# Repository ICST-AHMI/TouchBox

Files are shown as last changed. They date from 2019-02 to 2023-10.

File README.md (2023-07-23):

# The TouchBox MK3
A low-cost DIY interface for tracking the position multiple fingers (currently up to three) in contact with its top surface, measuring their contact areas as well as 3D (normal and lateral) forces, and providing rich vibrotactile feedback.

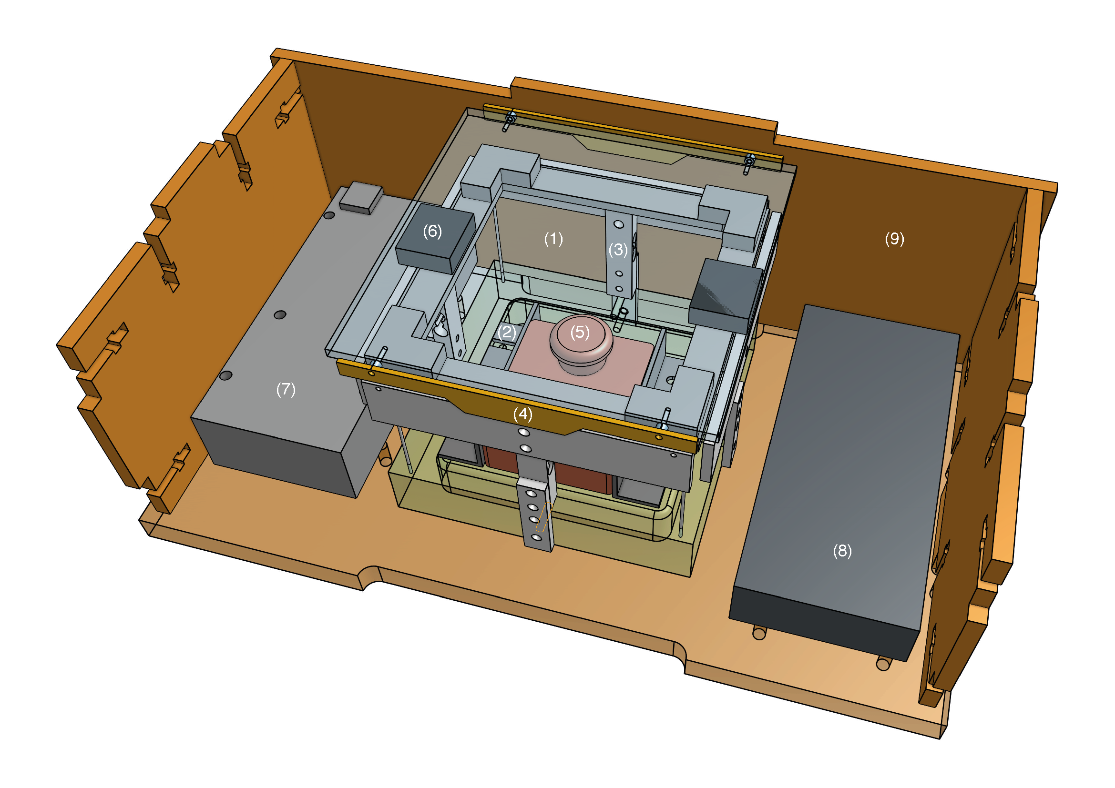
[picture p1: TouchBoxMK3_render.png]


---
## Content

* Software:
	1. GUI - based on [MaxMSP](https://cycling74.com) (No license required to run this patch).
	2. Example Patches for vibration and optional audio feedback.
	3. [Arduino](http://arduino.cc/) code.
	4. [OpenMV](https://openmv.io/) code.

* Hardware:
	1. list of required hardware (file HardwareList.md).
	2. 3D models (STEP) and plans (PDF) - made with [OnShape](https://onshape.com).
	3. electronics schematics - made with [Eagle](https://www.autodesk.com/products/eagle/overview).

* README.md (this).

---
## Software

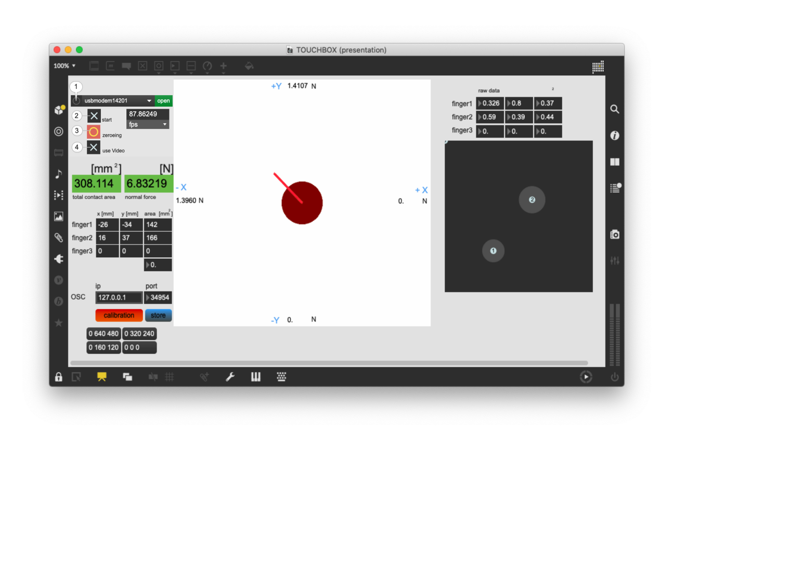
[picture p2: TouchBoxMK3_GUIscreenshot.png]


* Follow these steps:
	1. Refresh the list of available devices and select the Arduino (usually labeled 'usbmodem####');
	2. Toggle 'start';
	3. Reset force sensors. Press 'zeroing';
	4. For finger tracking via an openMV module, switch on 'use Video'.

* For sending the data to another application via OSC, enter ip and port numbers.

* If you need to calibrate the software, press "calibration" and once done "store".

## OSC communication protocol

### /touch/weight \<force>
force = float in [Newton]

### /touch/shear/up \<force>
force = float in [Newton]

### /touch/shear/down \<force>
force = float in [Newton]

### /touch/shear/left \<force>
force = float in [Newton]

### /touch/shear/right \<force>
force = float in [Newton]

### /touch/finger \<id> \<posX> \<posY> \<area>
id = int (identification id of finger, starts with 0)

posX = int in [pixel from center]

posY = int in [pixel from center]

area = float in [mm^2]

## Installation

For running the GUI, you need to install [MaxMSP](https://cycling74.com).
No license needed.

---
## Licenses

The Arduino and openMV code is licensed under [GNU](http://www.gnu.org/licenses/).

For everything else:  



---
## Release



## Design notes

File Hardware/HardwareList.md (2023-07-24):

# TouchBox MK3 hardware list

* Sensors
  * 1x normal force sensor - Micro Load Cell (5 kg) - Model CZL635
  * 4x lateral force sensor (one per side) - Micro Load Cell (780 g) - Model CZL616C
  * 1x OpenMV camera - Model M7 or compatible
  * 1x ultra wide angle lens for OpenMV camera

* Vibrotactile feedback
  * 2x compact voice-coil actuator (to be attached to the touch pannel) - Lofelt L5
  * 1x stereo amplifier - Dayton Audio DTA-2

* Misc electronics
  * 1x Arduino Mega 2560
  * 1x PCB - custom Arduino Mega shield
  * 2x PCB - custom for IR lighting touch panel
  * 5x amplifier for Micro Load Cells - Model INA125P-ND
  * 4x 43 Ohm Resistor for amplification of 780 g
  * 1x 75 Ohm Resistor for amplification of 5 kg
  * 12x IR LED's - (850nm) - Model SMD vsmy3850
  * Mac or Windows computer compatible with Cycling '74 Max.
  * 4ch audio interface (only required if separate audio stream is needed, if
    not you may go ahead with any internal audio interface)

* Custom hardware
  * 1x transparent touch panel - Plexiglass - 110 x 110 x 3 mm
  * 4x L-shaped distancers 20 x 20 x 10 mm + foam-rubber coupling spacers 2 mm
  * 1x shear base plate - steel slate 98 x 98 x 3 mm
  <!-- * 4x feather steel support rods 0.8 x 52 mm -->
  * 1x presure base support -  custom milled High Density Polyethylene block 100 x 100 x 20 mm
  <!-- * 1x normal force plate - custom milled aluminium block 85 x 85 x 2 mm -->
  * 4x side plate (shear sensor/support plate coupling element) - aluminium 96 x 20 x 3 mm
  * 4x shear sensor/pressure base coupling plates 35 x 9 x 3 mm
  * 2x L-shaped camera grips
  * MDF for optional laser-cut enclosure

* Off-the-shelf hardware
  * 3x distance washer - M5 x 18 mm
  * 1x countersink screw - M5 x 25 mm
  * 12x socket head cap screw - M4 x 25 mm
  * 4x countersink screw - mM4 x 30 mm
  * 4x feather steel wire (one per corner) - 0.8 x 35 mm
  * 4x actuator screw (two per actuator) - countersink screw - M3 x 40 mm
  * 4x rubber foam spacer (one at each corner)
  <!--* 8x headless screw (two per side plate) - M3 x 4 mm -->
  * 4x IR LED PCB screws - M2 x 10 mm
  * 4x IR LED PCB distance spacer - 2 mm
  * Cables and connectors as needed

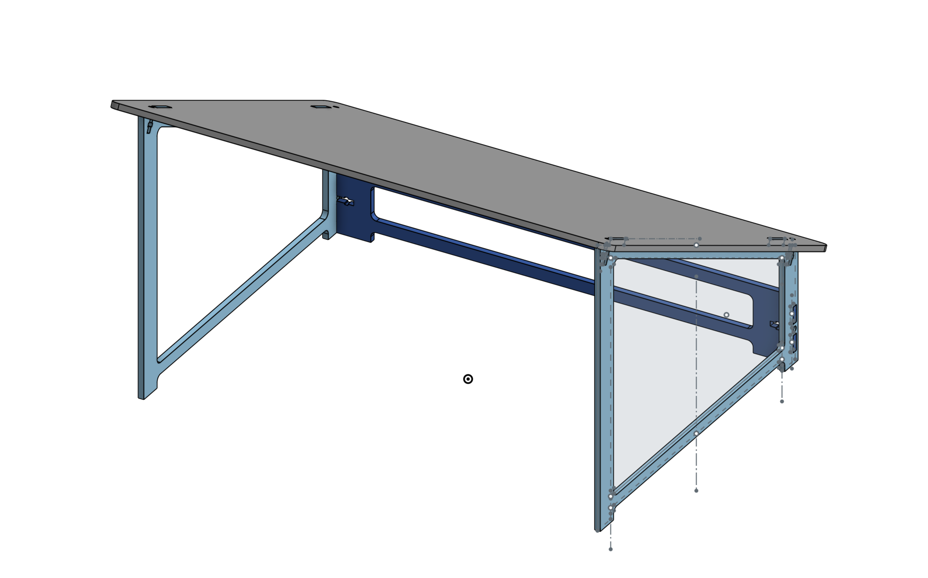
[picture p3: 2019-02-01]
Hardware/design/Shield/Shield.png

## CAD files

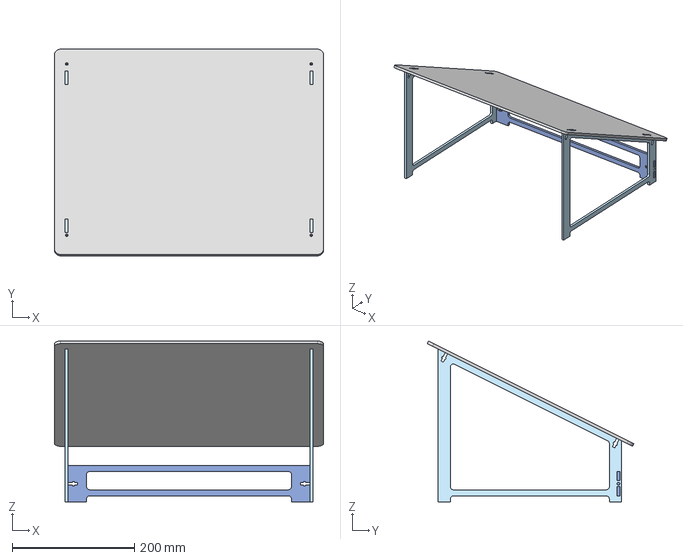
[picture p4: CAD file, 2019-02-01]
Hardware/design/Shield/Shield.step
440.0 x 338.0 x 263.3 mm

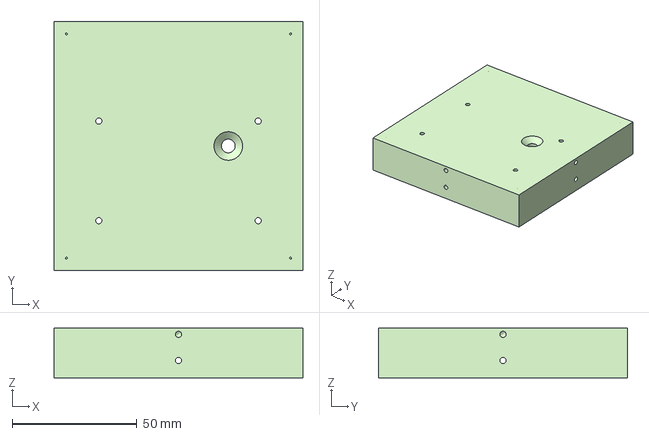
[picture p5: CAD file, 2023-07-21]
Hardware/design/TouchBox/PressureBase.step
100.0 x 100.0 x 20.0 mm

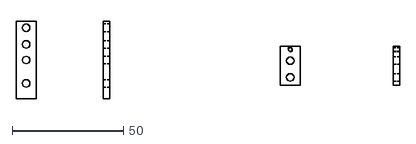
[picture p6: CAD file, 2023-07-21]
Hardware/design/TouchBox/ShearConnectors.dxf
172.5 x 35.0

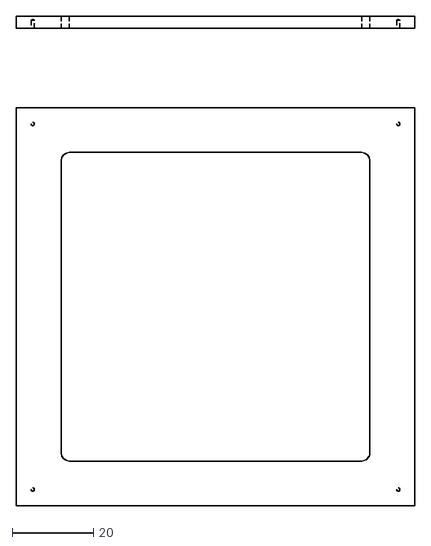
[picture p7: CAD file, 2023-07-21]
Hardware/design/TouchBox/ShearBase.dxf
98.0 x 120.5

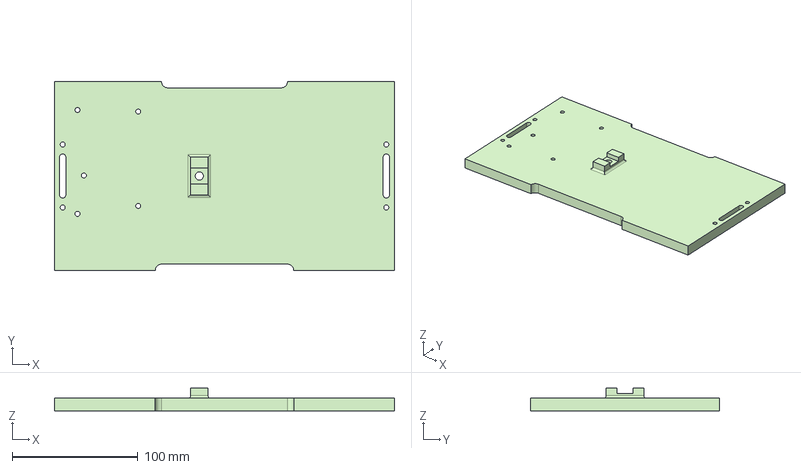
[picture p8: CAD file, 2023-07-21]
Hardware/design/TouchBox/Base.step
270.0 x 150.0 x 18.0 mm

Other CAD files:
Hardware/design/Shield/Shield.x_t

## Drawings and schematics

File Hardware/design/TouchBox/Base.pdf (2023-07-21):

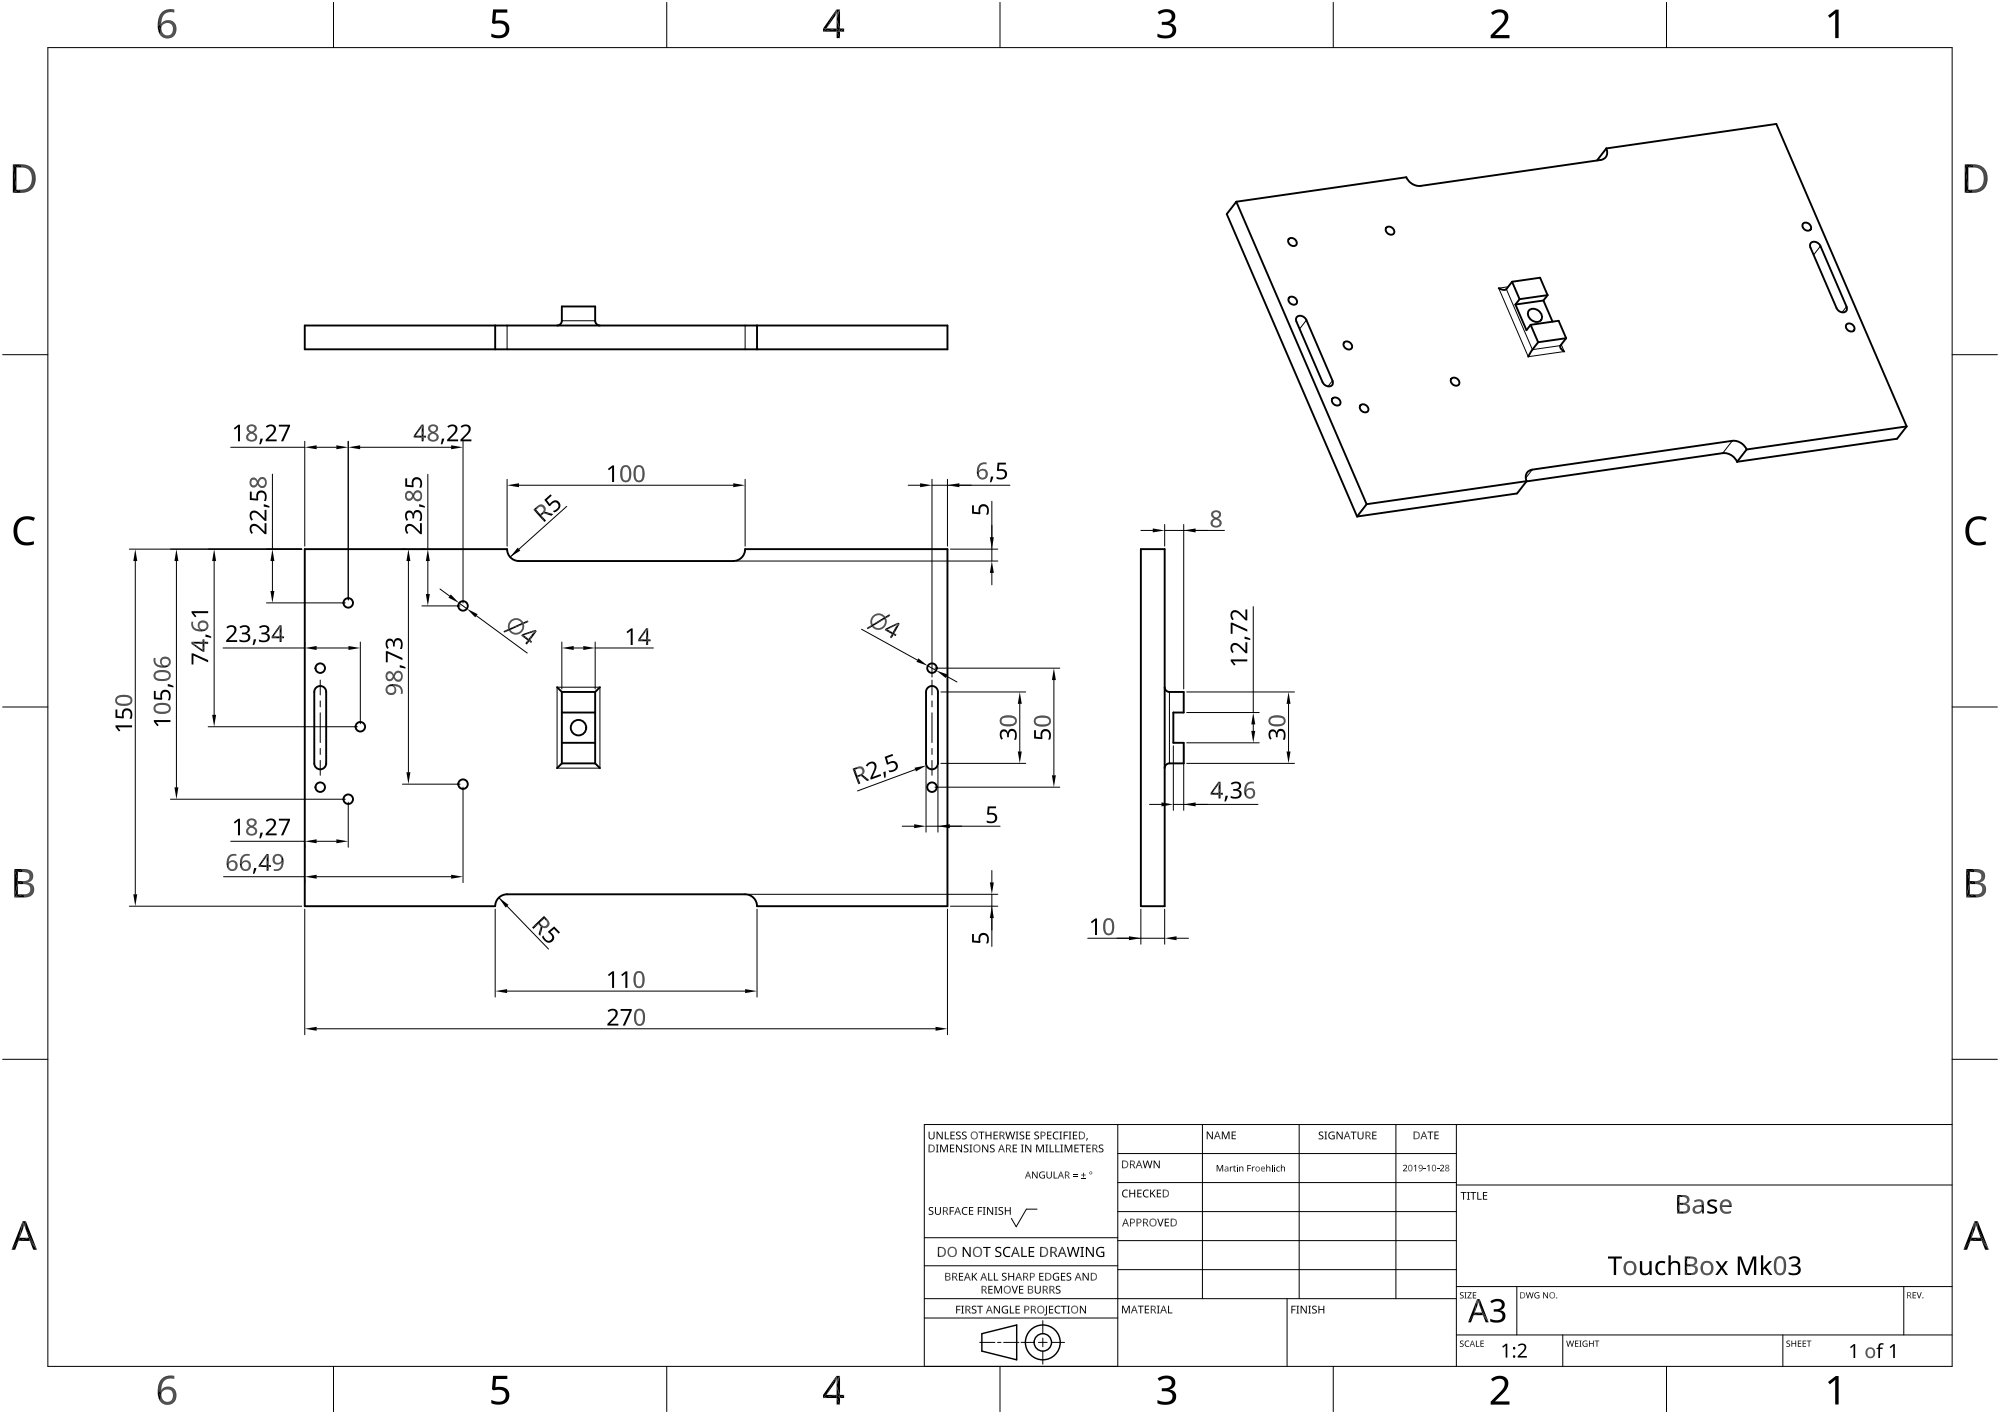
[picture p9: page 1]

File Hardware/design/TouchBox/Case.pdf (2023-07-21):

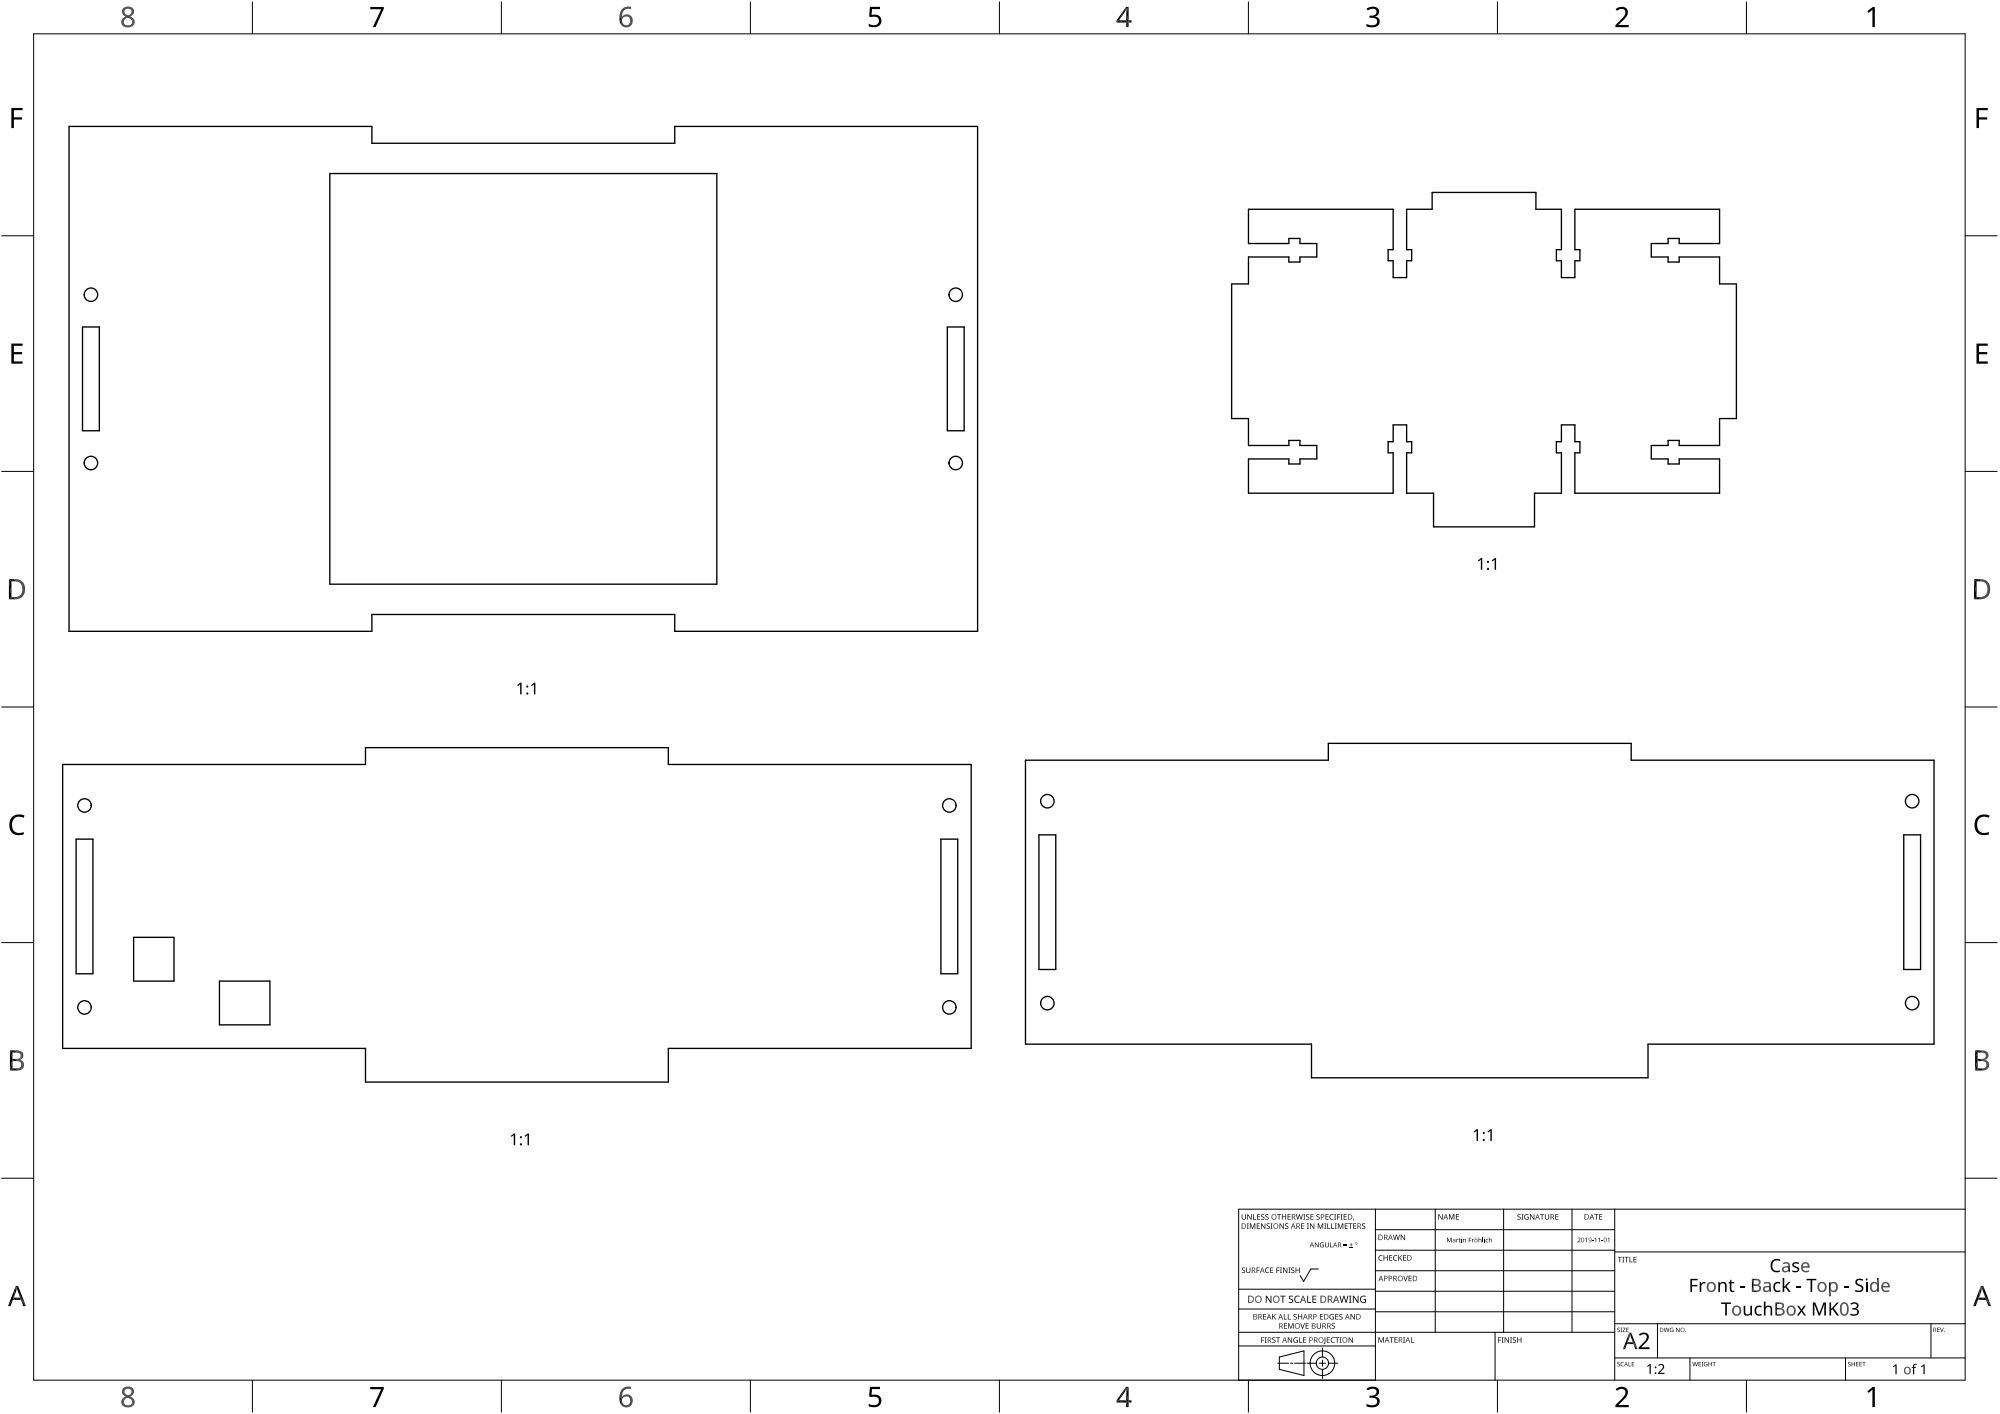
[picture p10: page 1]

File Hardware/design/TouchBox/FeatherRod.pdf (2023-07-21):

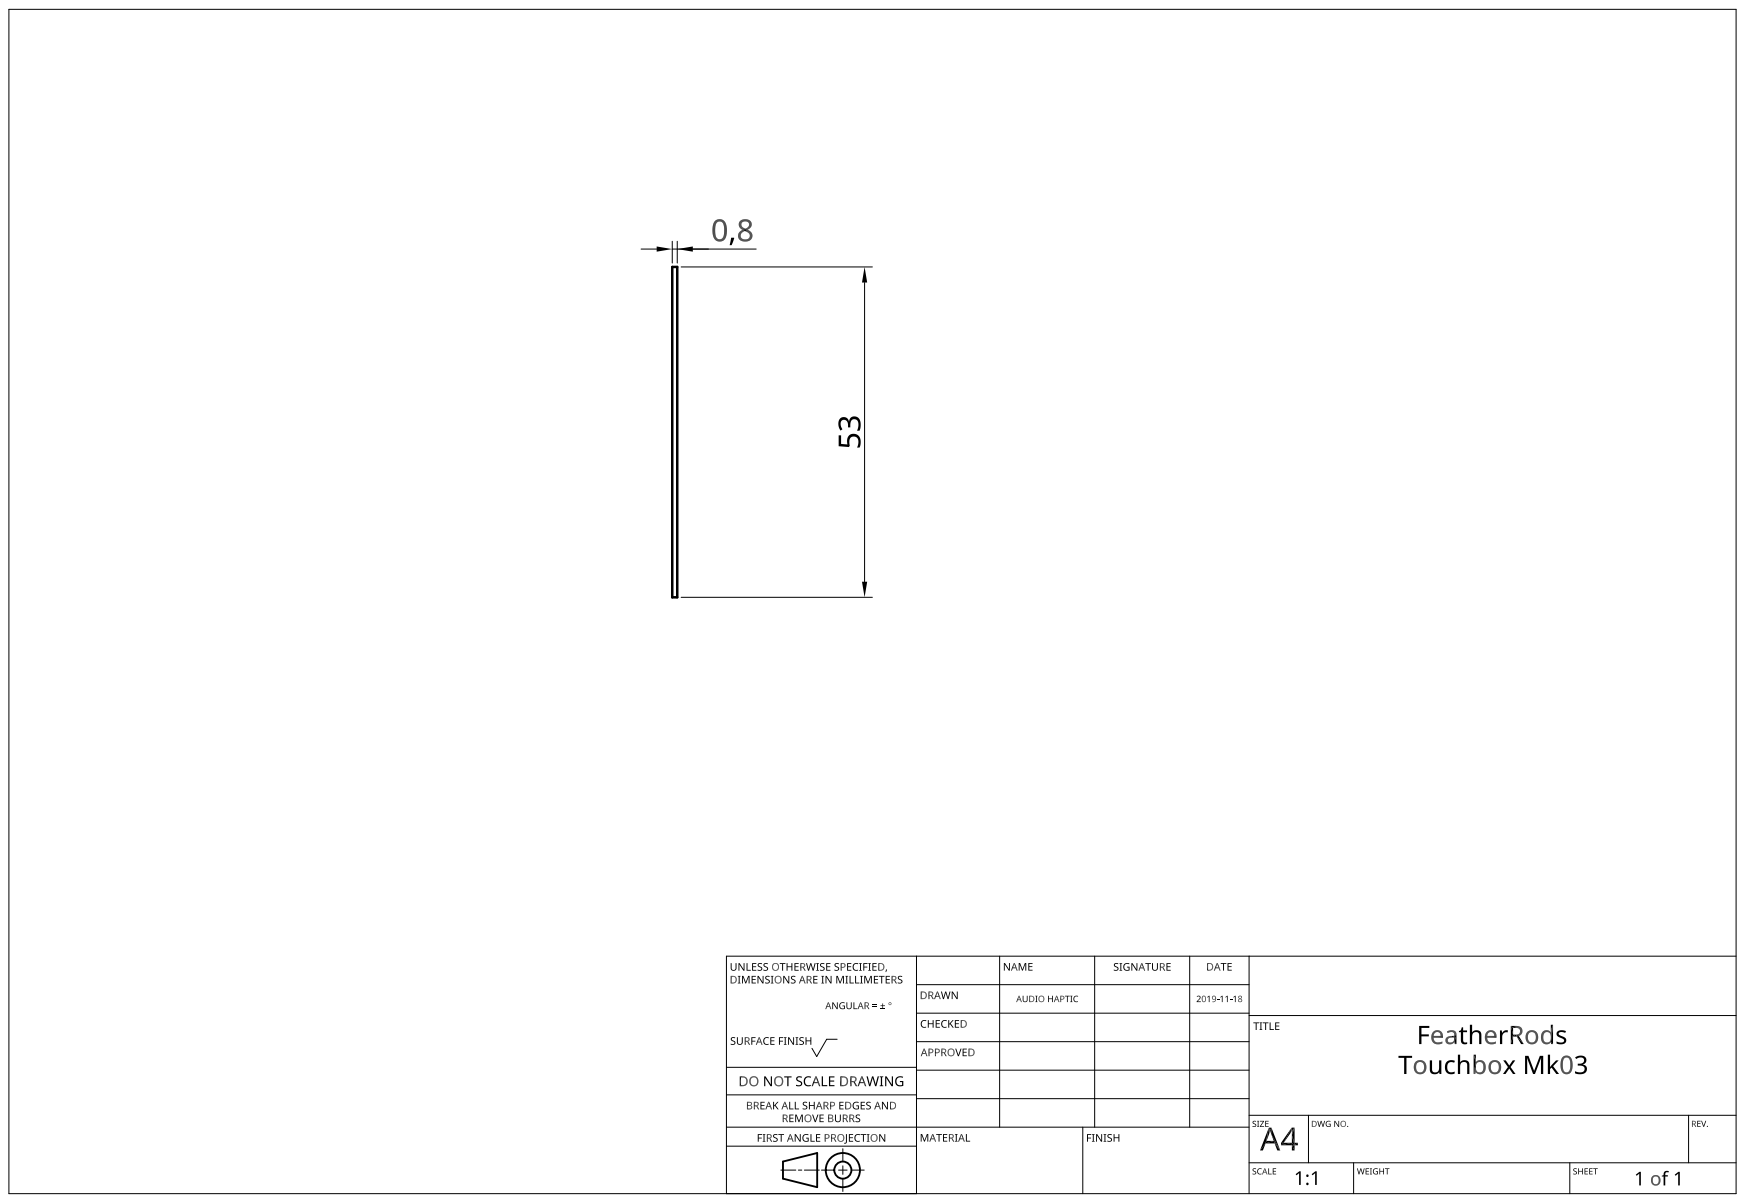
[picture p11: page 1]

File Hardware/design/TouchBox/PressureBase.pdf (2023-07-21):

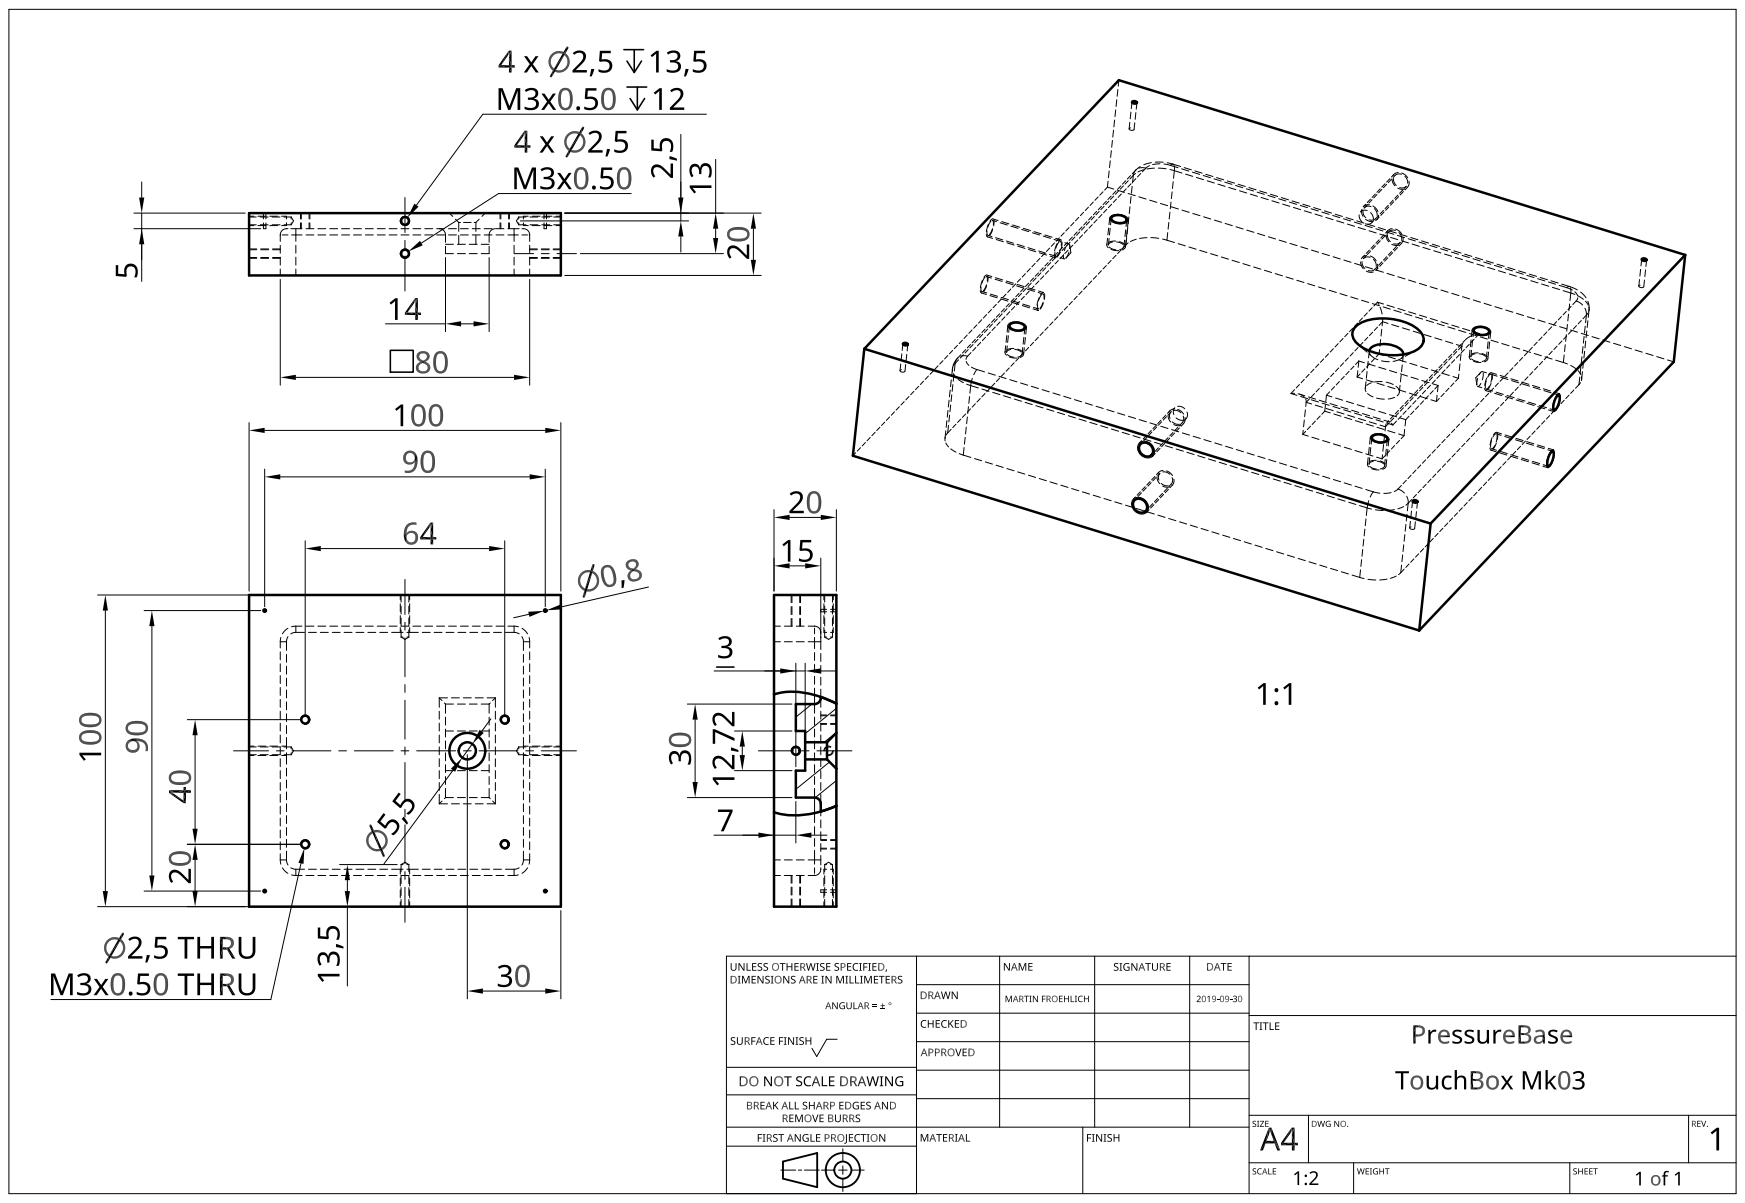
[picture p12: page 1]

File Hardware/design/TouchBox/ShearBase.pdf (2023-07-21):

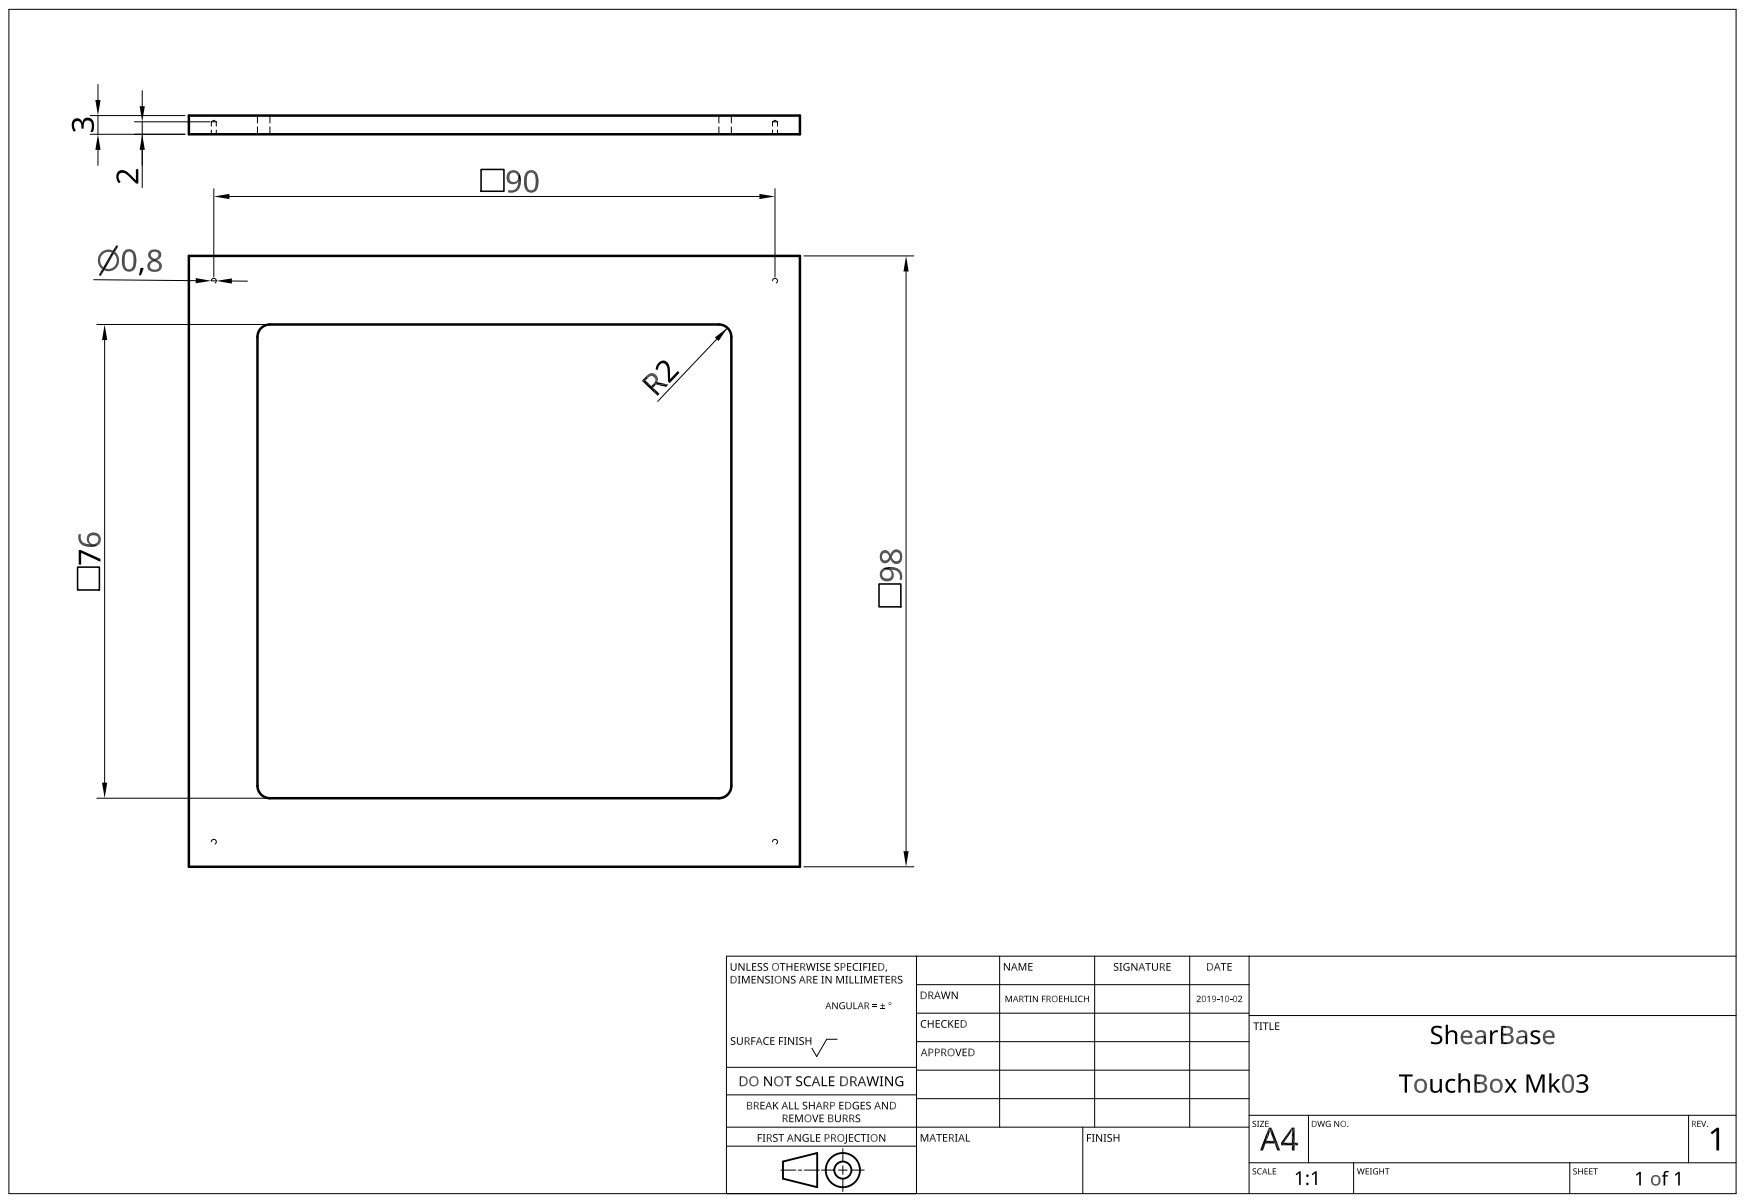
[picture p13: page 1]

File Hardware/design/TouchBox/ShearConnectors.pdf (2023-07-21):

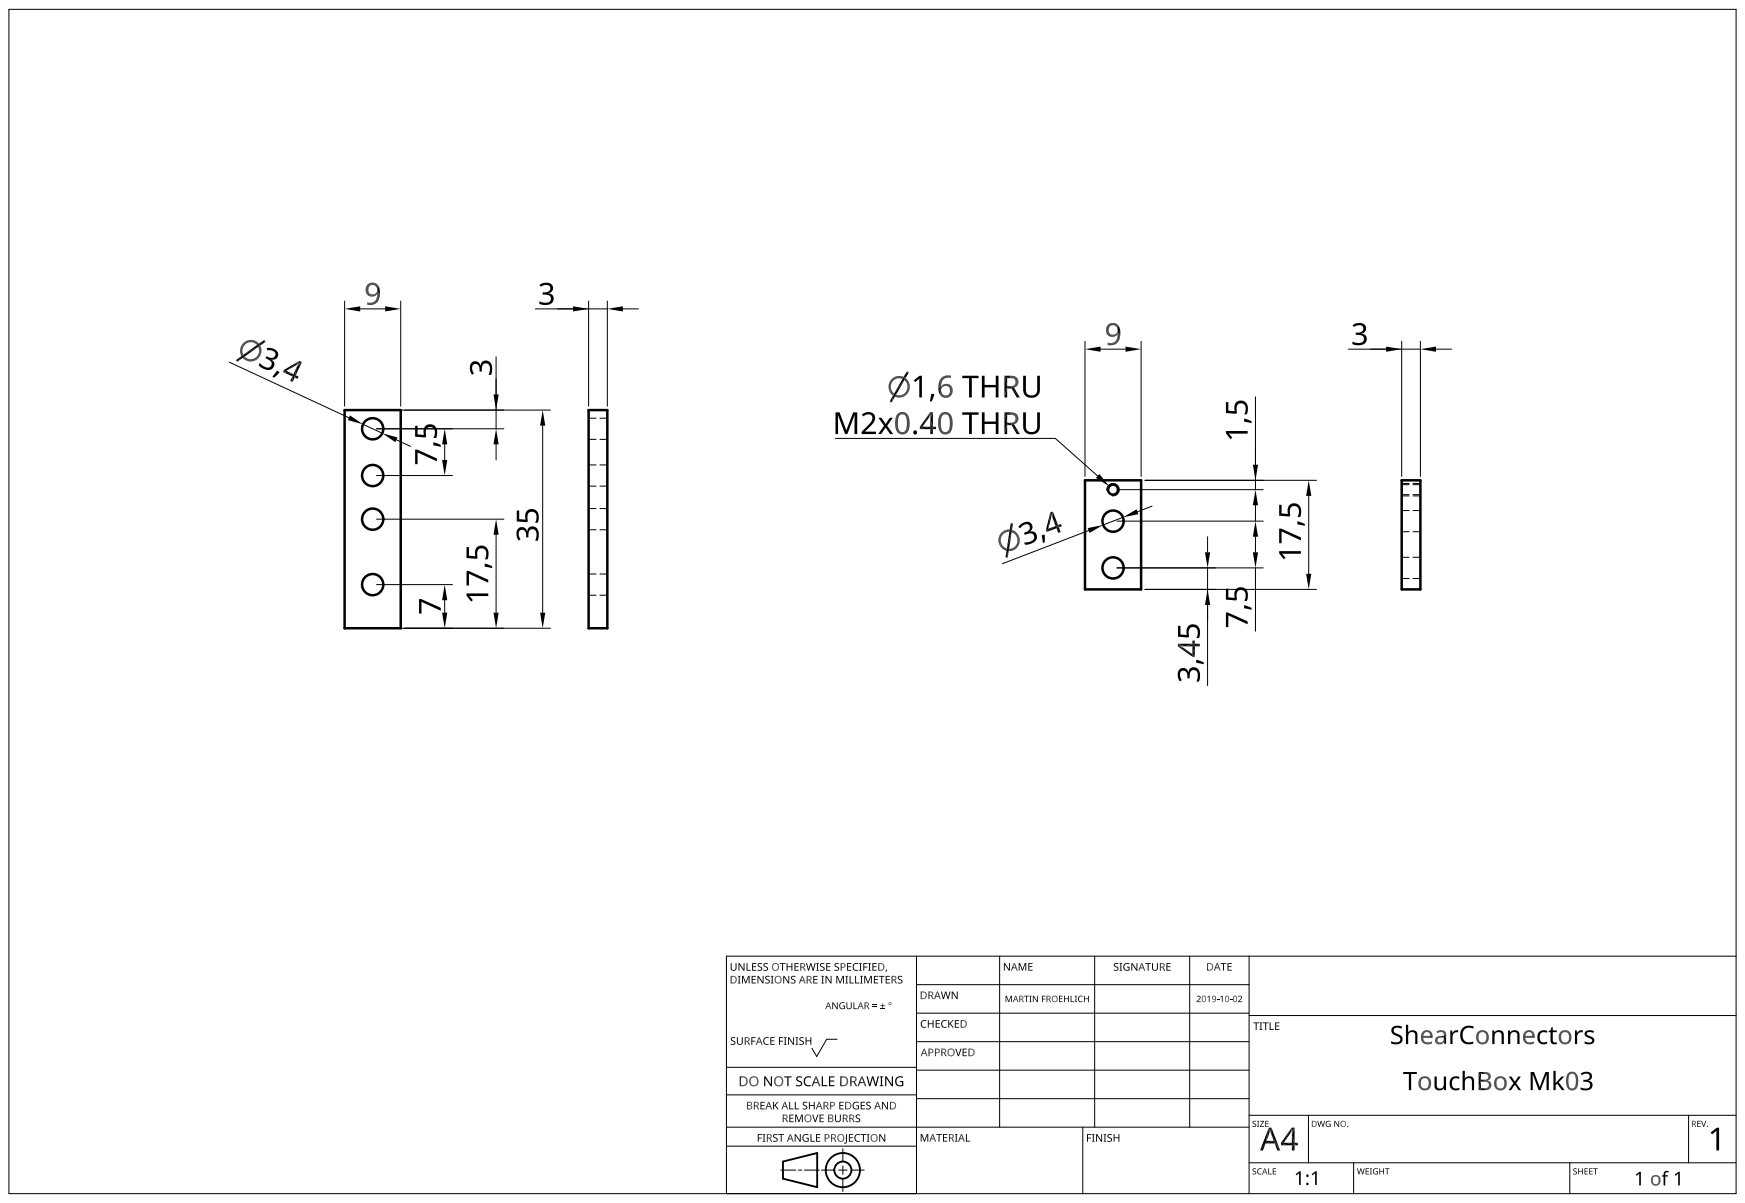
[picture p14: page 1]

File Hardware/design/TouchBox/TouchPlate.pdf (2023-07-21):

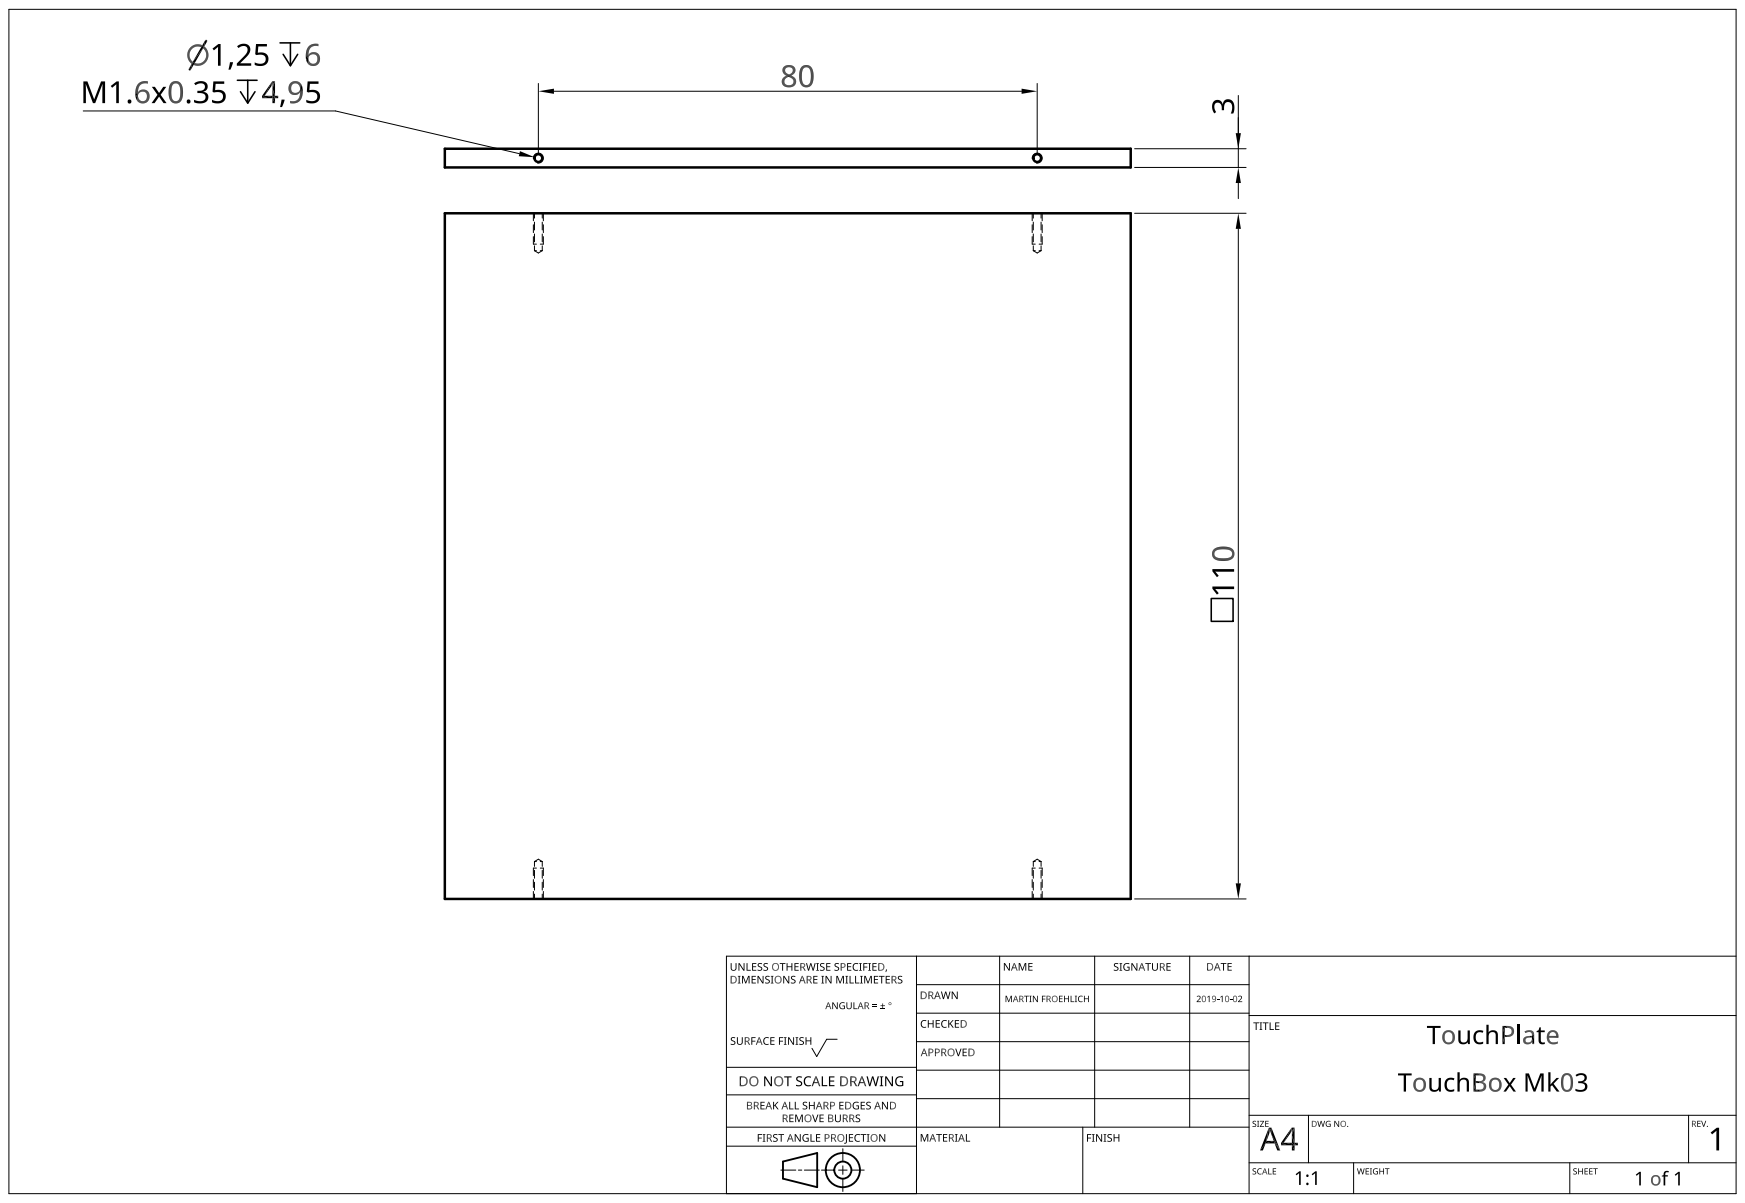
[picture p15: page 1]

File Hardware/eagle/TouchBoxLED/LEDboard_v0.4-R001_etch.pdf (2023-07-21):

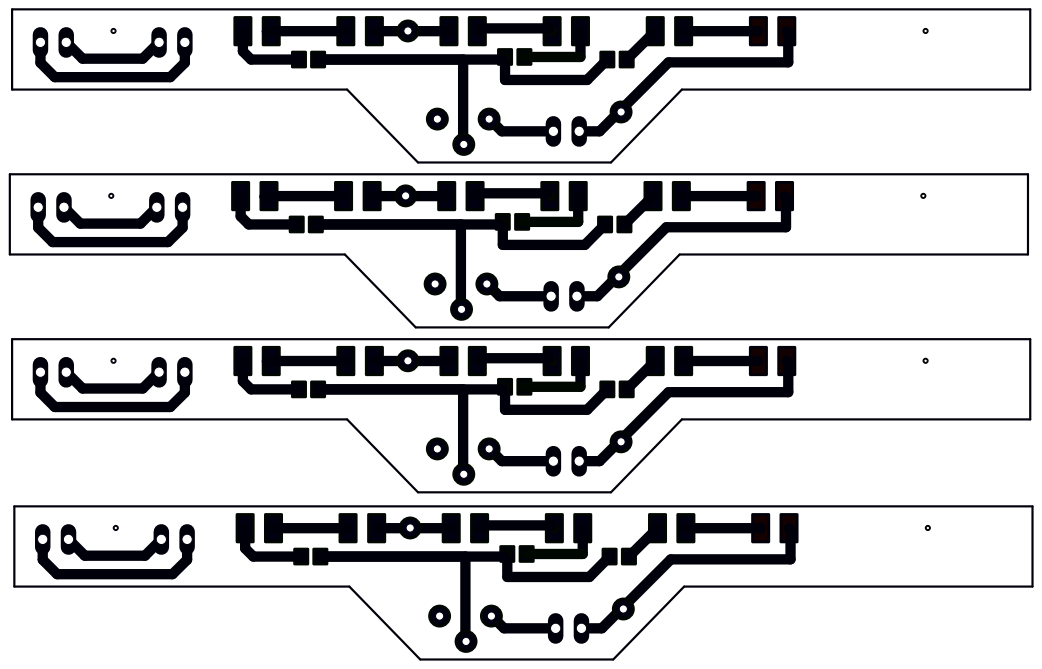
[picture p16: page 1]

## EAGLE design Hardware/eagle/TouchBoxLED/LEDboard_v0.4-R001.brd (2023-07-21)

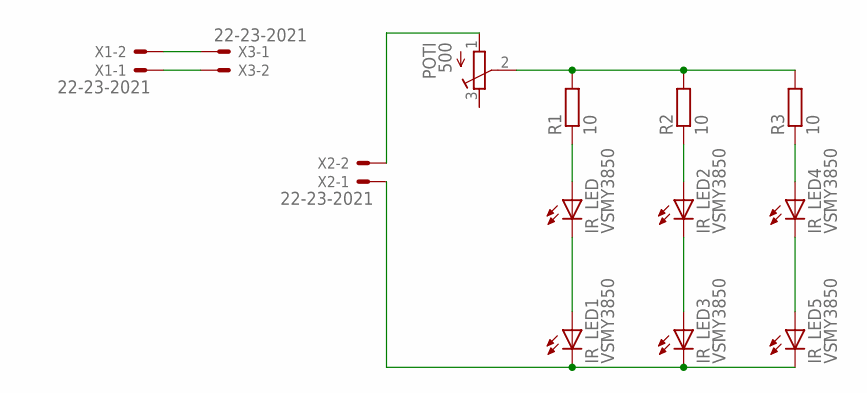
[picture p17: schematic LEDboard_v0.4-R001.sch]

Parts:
IR_LED, IR_LED1, IR_LED2, IR_LED3, IR_LED4, IR_LED5: VSMY3850; VSMY3850X
POTI: 500; RTRIM64Y
R1, R2, R3: 10; R0805
X1, X2, X3: 22-23-2021

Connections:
unnamed: IR_LED.2 (C), IR_LED1.1 (A)
unnamed: IR_LED.1 (A), R1.1
unnamed: IR_LED2.2 (C), IR_LED3.1 (A)
unnamed: IR_LED2.1 (A), R2.1
unnamed: IR_LED4.2 (C), IR_LED5.1 (A)
unnamed: IR_LED4.1 (A), R3.1
unnamed: POTI.2 (S), R1.2, R2.2, R3.2
unnamed: IR_LED1.2 (C), IR_LED3.2 (C), IR_LED5.2 (C), X2.1
unnamed: POTI.1 (A), X2.2
unnamed: X1.2, X3.1
unnamed: X1.1, X3.2

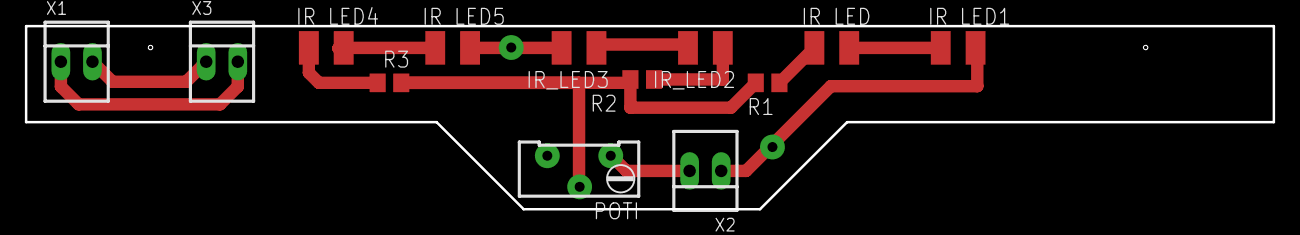
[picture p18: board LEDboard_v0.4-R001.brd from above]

Board: 2 copper layers, 100.3 x 14.7 mm, 13 parts (0 on the bottom side), 11 nets.

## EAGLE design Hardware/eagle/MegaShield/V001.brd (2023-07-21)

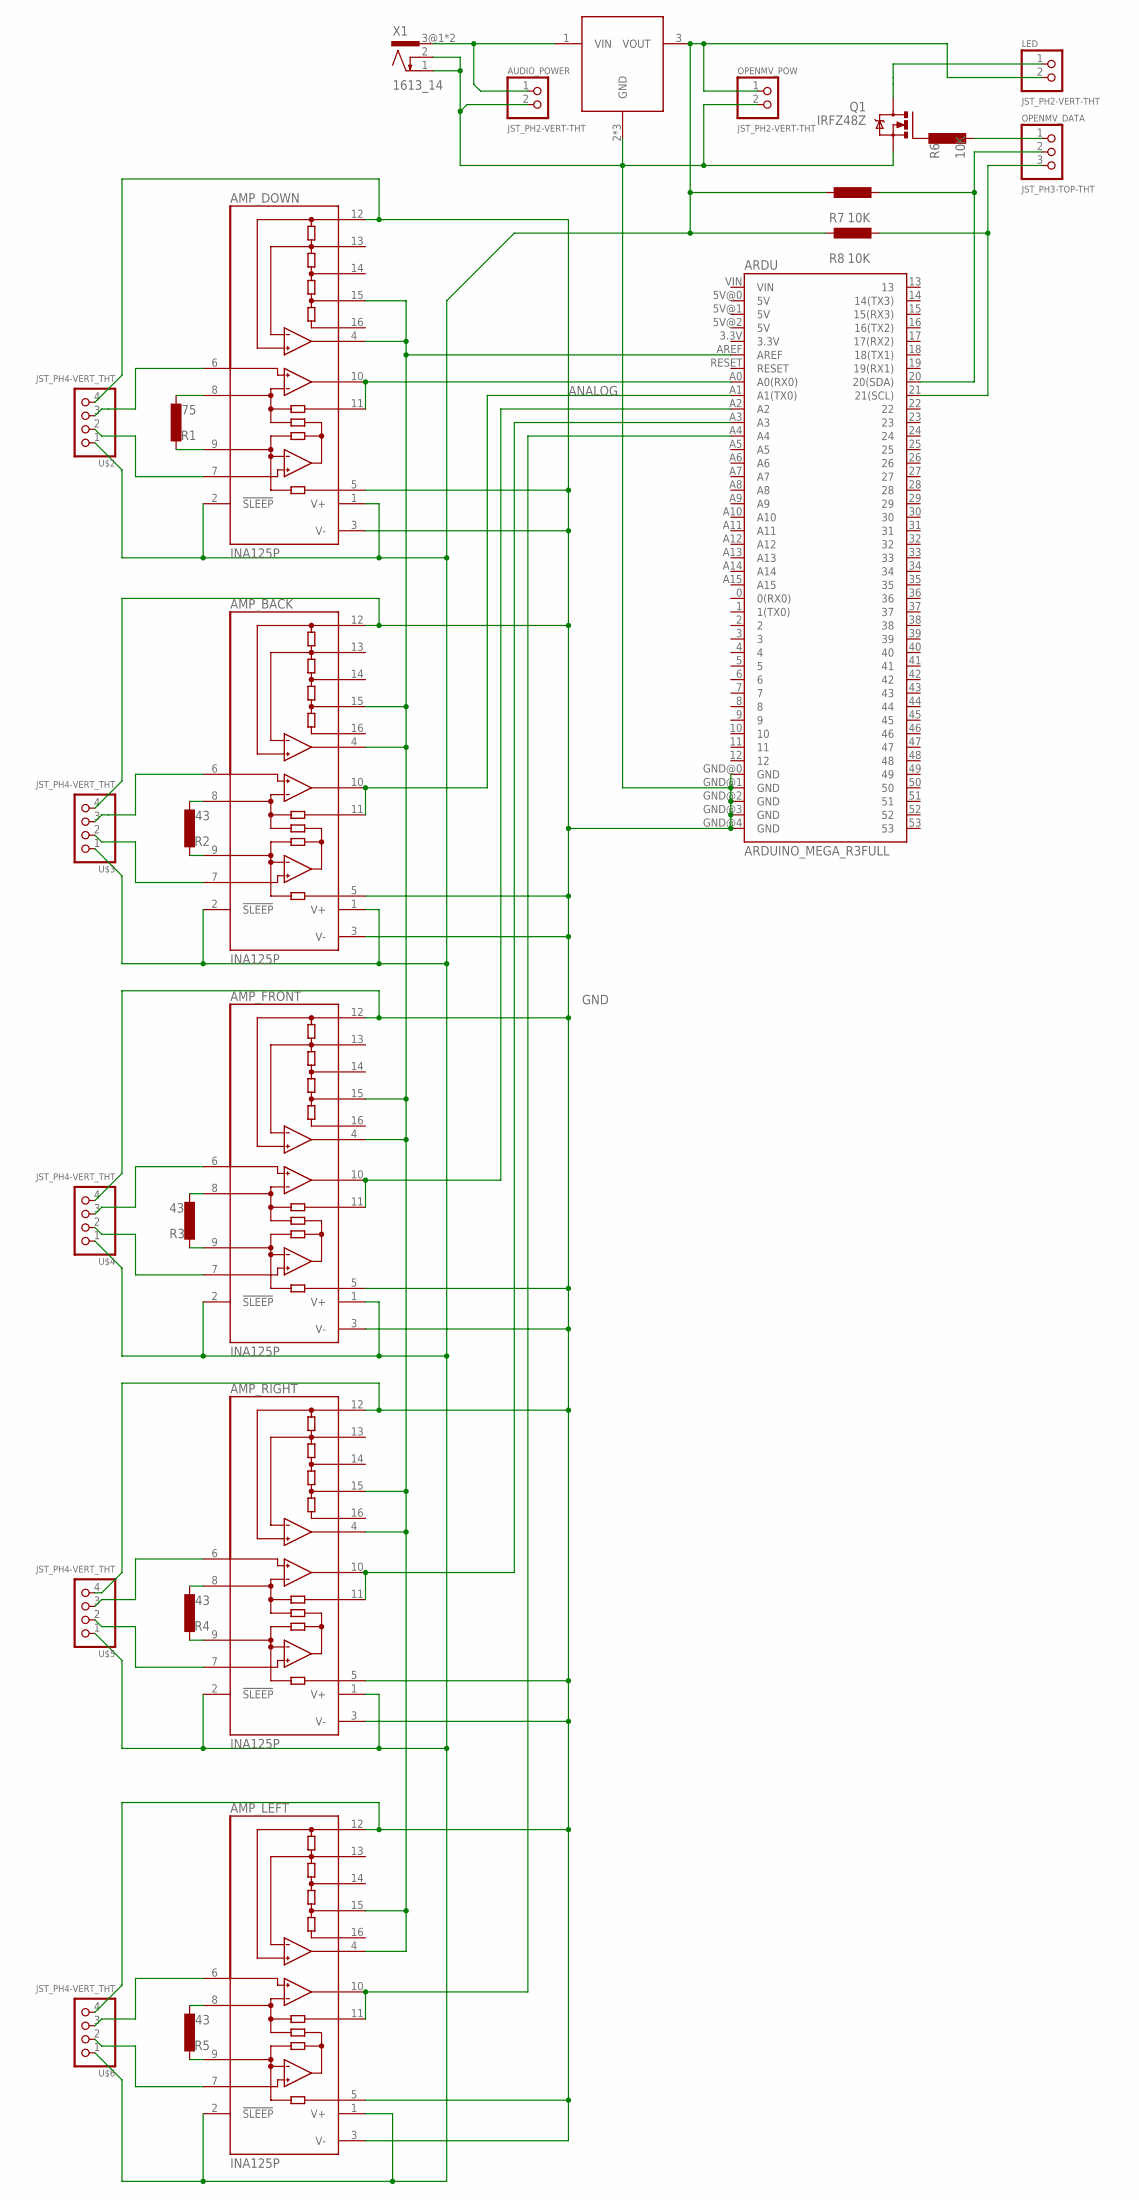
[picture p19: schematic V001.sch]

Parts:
AMP_BACK: INA125P; DIL16
AMP_DOWN: INA125P; DIL16
AMP_FRONT: INA125P; DIL16
AMP_LEFT: INA125P; DIL16
AMP_RIGHT: INA125P; DIL16
ARDU: ARDUINO_MEGA_R3FULL; ARDUINO_MEGA
AUDIO_POWER: JST_PH2-VERT-THT; B2B-PH-K-S
LED: JST_PH2-VERT-THT; B2B-PH-K-S
OPENMV_DATA: JST_PH3-TOP-THT; B3B-PH-K-S
OPENMV_POW: JST_PH2-VERT-THT; B2B-PH-K-S
Q1: IRFZ48Z; TO220BH
R1: 75; 0207/10
R2, R3, R4, R5: 43; 0207/10
R6, R7, R8: 10K; 0207/10
U$1: TL780; TO254P1651X1067X470-3
U$2, U$3, U$4, U$5, U$6: JST_PH4-VERT_THT; B4B-PH-K-S
X1: 1613_14

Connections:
5V: AMP_BACK.1 (V+), AMP_BACK.2 (!SLEEP), AMP_DOWN.1 (V+), AMP_DOWN.2 (!SLEEP), AMP_FRONT.1 (V+), AMP_FRONT.2 (!SLEEP), AMP_LEFT.1 (V+), AMP_LEFT.2 (!SLEEP), AMP_RIGHT.1 (V+), AMP_RIGHT.2 (!SLEEP), LED.2, OPENMV_POW.1, R7.1, R8.1, U$1.3 (VOUT), U$2.1, U$3.1, U$4.1, U$5.1, U$6.1
12V: AUDIO_POWER.1, U$1.1 (VIN), X1.3@1 (3), X1.3@2 (3)
ANALOG: AMP_DOWN.10 (OUT), AMP_DOWN.11 (SENSE), ARDU.A0 (A0(RX0))
AREF: AMP_BACK.4 (REFOUT), AMP_BACK.15 (REF5), AMP_DOWN.4 (REFOUT), AMP_DOWN.15 (REF5), AMP_FRONT.4 (REFOUT), AMP_FRONT.15 (REF5), AMP_LEFT.4 (REFOUT), AMP_LEFT.15 (REF5), AMP_RIGHT.4 (REFOUT), AMP_RIGHT.15 (REF5), ARDU.AREF
GND: AMP_BACK.3 (V-), AMP_BACK.5 (REF), AMP_BACK.12 (REFCOM), AMP_DOWN.3 (V-), AMP_DOWN.5 (REF), AMP_DOWN.12 (REFCOM), AMP_FRONT.3 (V-), AMP_FRONT.5 (REF), AMP_FRONT.12 (REFCOM), AMP_LEFT.3 (V-), AMP_LEFT.5 (REF), AMP_LEFT.12 (REFCOM), AMP_RIGHT.3 (V-), AMP_RIGHT.5 (REF), AMP_RIGHT.12 (REFCOM), ARDU.GND@0 (GND), ARDU.GND@1 (GND), ARDU.GND@2 (GND), ARDU.GND@3 (GND), ARDU.GND@4 (GND), AUDIO_POWER.2, OPENMV_POW.2, Q1.S, U$1.2 (GND), U$1.4 (GND), U$1.4.1 (GND), U$2.4, U$3.4, U$4.4, U$5.4, U$6.4, X1.1, X1.2
unnamed: AMP_DOWN.8 (RG), R1.2
unnamed: AMP_DOWN.9 (RG), R1.1
unnamed: AMP_BACK.8 (RG), R2.2
unnamed: AMP_BACK.9 (RG), R2.1
unnamed: AMP_DOWN.6 (+IN), U$2.3
unnamed: AMP_FRONT.8 (RG), R3.2
unnamed: AMP_FRONT.9 (RG), R3.1
unnamed: AMP_FRONT.10 (OUT), AMP_FRONT.11 (SENSE), ARDU.A2
unnamed: AMP_RIGHT.8 (RG), R4.2
unnamed: AMP_RIGHT.9 (RG), R4.1
unnamed: AMP_RIGHT.10 (OUT), AMP_RIGHT.11 (SENSE), ARDU.A3
unnamed: AMP_LEFT.8 (RG), R5.2
unnamed: AMP_LEFT.9 (RG), R5.1
unnamed: AMP_LEFT.10 (OUT), AMP_LEFT.11 (SENSE), ARDU.A4
unnamed: AMP_DOWN.7 (-IN), U$2.2
unnamed: OPENMV_DATA.1, R6.2
unnamed: AMP_BACK.10 (OUT), AMP_BACK.11 (SENSE), ARDU.A1 (A1(TX0))
unnamed: AMP_BACK.6 (+IN), U$3.3
unnamed: AMP_BACK.7 (-IN), U$3.2
unnamed: AMP_FRONT.6 (+IN), U$4.3
unnamed: AMP_FRONT.7 (-IN), U$4.2
unnamed: AMP_RIGHT.6 (+IN), U$5.3
unnamed: AMP_RIGHT.7 (-IN), U$5.2
unnamed: AMP_LEFT.6 (+IN), U$6.3
unnamed: AMP_LEFT.7 (-IN), U$6.2
unnamed: Q1.G, R6.1
unnamed: LED.1, Q1.D
unnamed: ARDU.20 (20(SDA)), OPENMV_DATA.2, R7.2
unnamed: ARDU.21 (21(SCL)), OPENMV_DATA.3, R8.2

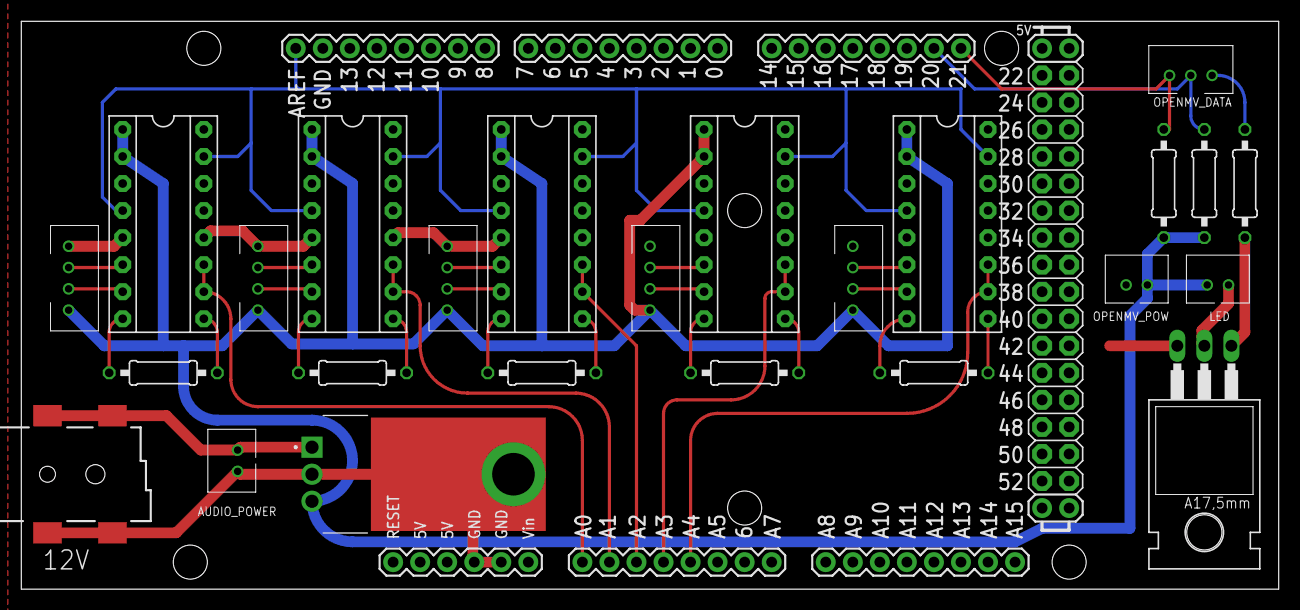
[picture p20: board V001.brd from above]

Board: 2 copper layers, 118.1 x 53.3 mm, 26 parts (0 on the bottom side), 34 nets.

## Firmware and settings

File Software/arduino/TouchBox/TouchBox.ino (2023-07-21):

//High performance analog data acquisition on the Arduino Duemilanove, with uniform 
//sampling rate.

//    Copyright (C) 
//        2011 Marco Civolani
//        2013 Martin Froehlich
//
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
//    Contacts:
//    Marco Civolani   - email: marcocivo@gmail.com
//    Stefano Papetti  - email: stefano.papetti@zhdk.ch
//    Martin Froehlich - email: martin.froehlich@zhdk.ch
//

//DESCRIPTION:
// Notice: this code was developed on the Arduino Uno, but possibly applies to 
// other versions as well.
//
// This Version compiles perfectly on Arduino 0022, but seems to have problems on newer Arduino Versions
//
// Since the Arduino API (as of May 2011) doesn't enable precise control over the ADC 
// sampling rate, this code bypasses the API and instead uses hardware interrupts. 
// By acting on some hardware registers (as done at the beginning of the 
// code) the ADC can be configured to work in "free running mode".
// In this way, the ADC is driven by a hardware timer (i.e. very precise) internal to the 
// Atmel chip, which at regular intervals asks to read the analog input(s).
// The timer frequency is selectable as a sub-multiple of the CPU frequency, by means of a
// multiplying factor set by the prescaler: i.e. everything is in sync with the 16 MHz
// quartz that provides the clock signal to the Atmel chip.
// When the ADC has the acquired value in its registers, it also raises an interrupt which
// is then intercepted by the function ISR(ADC_vect). In more detail the function does 
// what follows:
// - Puts the value in ADCValue;
// - Sends ADCValue via serial (together with the channel number, forming a 2 byte 
// packet);
// - Sets the value of the new channel from which the ADC will acquire data at the next
// round (i.e. polling on the first 4 channels).
// - Gets the values from SPI from the accelerometer
//
// Protocol structure:
// Byte1     Byte2
// 1ccccvvv  0vvvvvvv
// cccc       = 4  bit for channel info  0...15
// vvvvvvvvvv = 10 bit for value         0.....1023
//
// channel 0...4  values from ADC (ie. FSR's)
// channel 5...13 values from I2C (ie. openMV)
// channel 14 value tells how many blobs are sent from openMV
// channel 15 is currently free for future use
// 
// Please note that this firmware version was used for testing if the sampling rate was 
// actually stable.
// This was done by probing pin 12, so there's an extra line of code used for that:
// PORTB ^= 1 << PORTB4;
// which inverts the state of pin 12 at each execution of ISR(ADC_vect).
//


#include <avr/io.h>
#include <avr/power.h>
#include <avr/interrupt.h>

#include <Wire.h>

#define BAUD_RATE 115200
#define CHAR_BUF 128

// clear bit of special function register (sfr)
// _BV(bit) converts bit to byte
#ifndef cbi
#define cbi(sfr, bit) (_SFR_BYTE(sfr) &= ~_BV(bit))
#endif
// set bit of special function register (sfr)
#ifndef sbi
#define sbi(sfr, bit) (_SFR_BYTE(sfr) |= _BV(bit))
#endif 

//Assign the Chip Select signal to pin 10.
int CS=10;

//This is a list of some of the registers available on the ADXL345.
//To learn more about these and the rest of the registers on the ADXL345, read the datasheet!
char POWER_CTL = 0x2D;	//Power Control Register
char DATA_FORMAT = 0x31;
char DATAX0 = 0x32;	//X-Axis Data 0
char DATAX1 = 0x33;	//X-Axis Data 1
char DATAY0 = 0x34;	//Y-Axis Data 0
char DATAY1 = 0x35;	//Y-Axis Data 1
char DATAZ0 = 0x36;	//Z-Axis Data 0
char DATAZ1 = 0x37;	//Z-Axis Data 1

//Put the ADXL345 into +/- 2G range by writing the value 0x00 to the DATA_FORMAT register.
//   D7         D6   D5          D4  D3        D2      D1  D0
//   SELF_TEST  SPI  INT_INVERT  0   FULL_RES  Justify Range
// Range: 
//        0  0  =  2g
//        0  1  =  4g
//        1  0  =  8g
//        1  1  = 16g
char DATA_FORMAT_VALUE = B00000001; 

//This buffer will hold values read from the ADXL345 registers.
unsigned char SPIvalues[10];
//These variables will be used to hold the x,y and z axis accelerometer values.
int x,y,z;

int ADCValue;

int ADInterrupCounter = 0;

//void setup();
//void loop();

void setup()
{ 
  //Create a serial connection to display the data on the terminal.
  Serial.begin(BAUD_RATE);

  /******************************************************************************/

  DDRB |= 1 << PORTB4;  // the same as pinMode(12, OUTPUT);
  
  cli(); // disable interrupts while messing with their settings
  
  /********** ADC setup *********************************************************/
  
  /* internal pull-ups interfere with the ADC. disable the
  * pull-up on the pin if it's being used for ADC. either
  * writing 0 to the port register or setting it to output
  * should be enough to disable pull-ups. */
  PORTC = 0x00;
  DDRC = 0x00;
  
  //Control and Status Register A
  ADCSRA = 0;
  ADCSRB = 0; // Free-running mode
  
  PRR0 &= ~bit(PRADC);      // Disable ADC power reduction
  
  //Multiplexer Selection Channel
  ADMUX = 0<<ADLAR; // right-aligned
   
   // ADMUX |= 1<<REFS0 | 0<<REFS1; // internal Vcc reference (AVCC) = 5V
   // setting the reference Voltage to external:    
  analogReference(EXTERNAL);
   
  // All initialized. Set channel 0
  ADMUX |= 0<<MUX3 | 0<<MUX2 | 0<<MUX1 | 0<<MUX0;
   
  // Equivalences between values of prescaler and Fs (conversion time
  //  to scheme: 13.5 CPU cycles).
  // Fs = 16000kHz / 13.5 / per second
  //
  // Prescaler | ADPS2 | ADPS1 | ADPS0 |  Fs [kHz]
  // ------------------------------------------------
  //    2      |   0   |   0   |   0   |  592.59
  //    4      |   0   |   1   |   0   |  296.30
  //    8      |   0   |   1   |   1   |  148.15
  //    16     |   1   |   0   |   0   |  74.07
  //    32     |   1   |   0   |   1   |  37.04
  //    64     |   1   |   1   |   0   |  18.52
  //    128    |   1   |   1   |   1   |  9.26
  //
  // The above table shows the values of Fs to INTERNAL 'Arduino: 
  // Since the serial transmission requires CPU time for the REAL 
  // value of Fs one must consider the square wave with duty cycle to 50% 
  // generated at pin 12 via this firmware. Obviously, the duration 
  // of the period of this square wave depends on the value of 
  // the prescaler. From the measurements made with an oscilloscope, 
  // the following values are deduced:
  // ___________________
  // | Prescaler = 128 |
  // |_________________|
  // -------------------------------------------------------------
  // | WARNING: Fs is per channel.  Fs was calculated using      |
  // | the above table divided by the number of channels (4)!!   |
  // -------------------------------------------------------------
  //
  // TX baudrate [baud] |  Ts (per 4) [ms]  |  Fs (per channel) [Hz] 
  // ---------------------------------------------------------------
  //       9600         |    2.1            |          119
  //       19200        |    1.04           |          240
  //       38400        |    0.52           |          480
  //       57600        |    0.36           |          694
  //       115200       |    0.17           |          1470
  //
  // NOTE: To receive data during the measurements with the oscilloscope
  // a Pd- Patch was used that can write data to a file (writeToFile.pd)
   
  ADCSRA |= 1<<ADPS2;
  ADCSRA |= 1<<ADPS1;
  ADCSRA |= 1<<ADPS0;
  
  ADCSRA |= 1<<ADATE;      // Autotrigger enabled
  ADCSRA |= 1<<ADIF;       // ADC interrupt flag is cleared
  ADCSRA |= 1<<ADIE;       // ADC interrupt capability is activated
  
  // Free running mode
  ADCSRB |= 0<<ADTS2;
  ADCSRB |= 0<<ADTS1;
  ADCSRB |= 0<<ADTS0;
   
  ADCSRA |= 1<<ADEN;       // ADC enabled

  /******************************************************************************/
  
  sei(); // turn interrupts back on

  ADCSRA |= 1<<ADSC;       // Conversion started  

  Wire.begin();
  delay(1000); // Give the OpenMV Cam time to bootup.
}

/**
 * Inside the loop we will only send the recieved I2C commands from the openMC device
 */
void loop() {
  int32_t temp = 0;
  char buff[CHAR_BUF] = {0};

  Wire.requestFrom(0x12, 2);
  if(Wire.available() == 2) { // got length?

    temp = Wire.read() | (Wire.read() << 8);
 
    Wire.requestFrom(0x12, temp);
    if(Wire.available() == temp) { // got full message?

      temp = 0;
      while(Wire.available()) buff[temp++] = Wire.read();
      
      // the structure of the buffer is: <id>|<centroidX>|<centroidY>|<pixels>|<numberOfBlobs>
      String str = String(buff);
      String index = str.substring(0, str.indexOf("|"));
      str = str.substring(str.indexOf("|") + 1, str.length());
      String centroidX = str.substring(0, str.indexOf("|"));
      str = str.substring(str.indexOf("|") + 1, str.length());
      String centroidY = str.substring(0, str.indexOf("|"));
      str = str.substring(str.indexOf("|") + 1, str.length());
      String pixels = str.substring(0, str.indexOf("|"));
      String numberOfBlobs = str.substring(str.indexOf("|") + 1, str.length());

      byte i = (byte) index.toInt();

      // we send the total number of blobs detected, though we can only 
      // send the data for the first three.
      int numOfB = numberOfBlobs.toInt();
      TX(numOfB, 14);
      
      if(i < 3){ 
        // we can only transfer 3 blobs through our data protocol
        int cx = centroidX.toInt();
        int cy = centroidY.toInt();
        int pix = pixels.toInt();
        // we send in this order, so on maxmsp side, we can simply put the
        // finger info into a [pack i i i] - object
        TX(pix,7 + i * 3);
        TX(cy, 6 + i * 3);
        TX(cx, 5 + i * 3);
      }

    } else {
      while(Wire.available()) Wire.read(); // Toss garbage bytes.
    }
  } else {
    while(Wire.available()) Wire.read(); // Toss garbage bytes.
  }
}


void TX(int value, byte channel)
{
  byte LSB, MSB;
  int tmpVal;
  
  LSB = 0;
  //shift the channel number three places to the left
  // B100000000 | B0000cccc -> B1cccc000
  MSB = B10000000 | (channel << 3); 
    
  // take the top 3 bits only (vvv0000000)
  tmpVal = value & 896;
  // and shift it 7 bits to the right (00000vvv)
  tmpVal = tmpVal >> 7;
  // and add it to the MSB 
  MSB = MSB | tmpVal; // B1cccc000 | B00000vvv -> B1ccccvvv
  
  // then store only the lower 7 bits of the value
  LSB = value & B01111111; // Bvvvvvvvvvv & B0001111111 -> B0vvvvvvv

  Serial.write(MSB);
  Serial.write(LSB);
}

//interrupt function call
ISR(ADC_vect)
{
  ADInterrupCounter++;
  if(ADInterrupCounter >= 5){
    ADInterrupCounter = 0;
    
    //sendSPI();
    
    cli();// disable interrupts while messing with their settings
  
    ADCValue = ADCL;       // get low register first
    ADCValue += ADCH << 8; // and then add the high register
        
    //TX(ADCValue, ADMUX & B00001111);       // Questa sarebbe l'istruzione corretta...
    //TX(ADCValue, ((ADMUX & B00001111)-1)%3); // Pezza per recuperare il valore corretto
                                             // del canale: colpa di Arduino che spedisce
                                             // il valore sul canale sbagliato
 
//    Serial.println("nextframe: " + ADCValue);
    TX(ADCValue, ADMUX & B00001111);
        
    //The following code is used for channel selection.
    
    // Seleziono nuovo canale di acquisizione.
    // La prossima conversione avverrà su tale canale.
    if((ADMUX & B00001111) == B00000000)
    {
      cbi(ADCSRA,ADSC);
      cbi(ADMUX,MUX3);
      cbi(ADMUX,MUX2);
      cbi(ADMUX,MUX1);
      sbi(ADMUX,MUX0);
      sbi(ADCSRA,ADSC);
    }
    
    else if((ADMUX & B00001111) == B00000001)
    {
      cbi(ADCSRA,ADSC);
      cbi(ADMUX,MUX3);
      cbi(ADMUX,MUX2);
      sbi(ADMUX,MUX1);
      cbi(ADMUX,MUX0);
      sbi(ADCSRA,ADSC);
    }
    
    else if((ADMUX & B00001111) == B00000010)
    {
      cbi(ADCSRA,ADSC);
      cbi(ADMUX,MUX3);
      cbi(ADMUX,MUX2);
      sbi(ADMUX,MUX1);
      sbi(ADMUX,MUX0);
      sbi(ADCSRA,ADSC);
    }
    
    else if((ADMUX & B00001111) == B00000011)
    {
      cbi(ADCSRA,ADSC);
      cbi(ADMUX,MUX3);
      sbi(ADMUX,MUX2);
      cbi(ADMUX,MUX1);
      cbi(ADMUX,MUX0);
      sbi(ADCSRA,ADSC);
    }

    else if((ADMUX & B00001111) == B00000100)
    {
      cbi(ADCSRA,ADSC);
      cbi(ADMUX,MUX3);
      cbi(ADMUX,MUX2);
      cbi(ADMUX,MUX1);
      cbi(ADMUX,MUX0);
      sbi(ADCSRA,ADSC);
    }
        
    // DEBUG: clock dell'ADC in uscita su pin 12: alza il pin 12 se basso,
    // altrimenti lo abbassa.
    PORTB ^= 1 << PORTB4;  // the same as digitalWrite(12, HIGH if LOW or LOW if HIGH)
    
    sei();// turn interrupts back on
  }
}

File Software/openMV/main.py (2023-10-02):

# Multi Color Blob Tracking for TouchBox Mk03
#
# This code does  multi color blob tracking using the OpenMV Cam.
#
# it also will switch on and off the external infraRed Leds in sync with the framerate
# thanks to this thread: http://forums.openmv.io/viewtopic.php?f=6&t=1023&p=6360
#
# AND sends the gathered data via I2C to the attached arduino:
#
# Please wire up your OpenMV Cam to your Arduino like this:
#
# OpenMV Cam Master I2C Data  (P5) - Arduino Uno Data  (A4)
# OpenMV Cam Master I2C Clock (P4) - Arduino Uno Clock (A5)
# OpenMV Cam Ground                - Arduino Ground

# # # TO DO / NOTES :
# - all PIXEL BASED VALUES need to be ajustable for changing resolution (and x-flipped image)
# - TWEAK THRESHOLDS, i.e. find_blobs(threholds, area_threshold, pix_threshold)
# --> see: Tools > MAchine Vision > Threshold Editor
# --> adaptive thresholding? (NOTE that sensor gain is set on power up, so changing the lighting
#     conditions will likely cause problems) --> maybe need a reset button?
# - maybe define flags as constants to speed up code? (THERE ARE NO CONSTANTS IN PYTHON?)
# - look into image.mask_rectangle/circle/ellipse() for better masking once everything is fixed...
# - frame differencing - see: image.sub() & image.difference()
# - look into using sensor feedback to activate find_blobs(), or to create a a bg mask...
# --> would have to think more about how this would work b/c hand might obsucre some lights that
#     were causing false positives (and actual blobs could be in the same location and be ignored)

import sensor, image, time, ustruct

from pyb import I2C
from pyb import LED
from pyb import Pin

red_led   = LED(1)
green_led = LED(2)
blue_led  = LED(3)
ir_led    = LED(4)

green_led.on()
time.sleep_ms(2500)
green_led.off()

# debugging
print_blob_info = False

# manage ir_led state
use_bg_subtraction = False
ir_led_active = True

# set up lens correction and resolution
use_lens_corr = True
use_hi_res = False #original
display_grid_lines = False

# draw blobs on screen
draw_blobs = True

# blob thresholds
blob_pixels_threshold = 50 #default = 50
blob_area_threshold = 50 #default = 50

# sensor stuff:
start_delay_time = 2500
sensor_flip_X = True

if use_lens_corr: # setup ROI (low/high res + lense cor)
    roi_x = [20,24]  #default = [20,12] --> [20,24]?
    roi_y = [0,3]
else: # setup ROI (low/high res + NO lense cor)
    roi_x = [30,24]
    roi_y = [0,20]
    #roi_x = [60,48]
    #roi_y = [0,20]

if use_hi_res:
    roi_x[0] *= 2
    roi_x[1] *= 2
    roi_y[0] *= 2
    roi_y[1] *= 2

#print('bool test: bool(0) = ' + str(bool(0)) + ', not 0 = ' + str(not 0))

#img_mask = (roi_x[0], roi_y[0], img.width() - (roi_x[0] + roi_x[1]), img.height() - (roi_y[0] + roi_y[1]))

print('roi_x: ' + str(roi_x) + ' ~ sum: ' + str(roi_x[0] + roi_x[1]))
print('roi_y: ' + str(roi_y) + ' ~ sum: ' + str(roi_y[0] + roi_y[1]))
#print('roi_mask: ' + str(img_mask))


# define dims for scale fac
# # # image size: w = 160, h = 120
num_squares = 5 # each square is 10 x 10 mm
x_min = 30 # pixel
x_max = 141 # pixel
delta_x = x_max - x_min # pixels
x_scale_fac = 1 / ((delta_x / num_squares) / 10) # mm/pixels # div is slow, so set scale_fac up so it can be multiplied later...
y_min = 6 # pixel
y_max = 117 # pixel
delta_y = y_max - y_min # pixels
y_scale_fac = 1 / ((delta_y / num_squares) / 10) # mm/pixels

overall_scale_fac = (x_scale_fac + y_scale_fac) / 2 # mm/pixels

lens_corr_strenght = 2.50
lens_corr_zoom = 1

# NOTE with these values the x & y scale factors are the same
print('x_scale_fac: ' + str(x_scale_fac) + ' mm/pixel')
print('y_scale_fac: ' + str(y_scale_fac) + ' mm/pixel')
print('overall_scale_fac: ' + str(overall_scale_fac) + ' mm/pixel')



thresholds = [(160, 255)] # try for grayscale

# Color Tracking Thresholds (L Min, L Max, A Min, A Max, B Min, B Max)
#thresholds = [(83, 100, -30, 30, -30, 30)] # try modifying to make detection more robust
#thresholds = [(94, 100, -30, 30, -30, 30)] # try modifying to make detection more robust
# --> THRESHOLDS SEEM TO BE VERY DEPENDANT ON AMBIENT LIGHT

# The below thresholds track in general red/green things. You may wish to tune them...
#thresholds = [(83, 100, -4, 9, -16, 8)] # original thresholds from martin

#thresholds = [(30, 100, 15, 127, 15, 127), # generic_red_thresholds
#             (30, 100, -64, -8, -32, 32), # generic_green_thresholds
#              (0, 15, 0, 40, -80, -20)] # generic_blue_thresholds
# You may pass up to 16 thresholds above. However, it's not really possible to segment any
# scene with 16 thresholds before color thresholds start to overlap heavily.

sensor.reset()
#sensor.set_pixformat(sensor.RGB565) # original
sensor.set_pixformat(sensor.GRAYSCALE) # try w/ grayscale...
if use_hi_res:
    sensor.set_framesize(sensor.QVGA) # hi-res version: 320 x 240
    print('hi res mode: 320 x 240')
    #sensor.set_framesize(sensor.VGA) # extra hi-res version: 640 x 480 (grayscale only!)
    #print('hi res mode: 640 x 480')
else:
    sensor.set_framesize(sensor.QQVGA) # low-res version: 160 x 120
    print('low res mode: 160 x 120')

sensor.set_hmirror(sensor_flip_X) # mirror x-axis
sensor.skip_frames(time = start_delay_time)
sensor.set_auto_gain(False) # must be turned off for color tracking
sensor.set_auto_whitebal(False) # must be turned off for color tracking
sensor.set_auto_exposure(False, exposure_us=2000) # make smaller to go faster

img = sensor.snapshot()
img_mask = (roi_x[0], roi_y[0], img.width() - (roi_x[0] + roi_x[1]), img.height() - (roi_y[0] + roi_y[1]))
print('roi_mask: ' + str(img_mask))

clock = time.clock()

# Only blobs that with more pixels than "pixel_threshold" and more area than "area_threshold" are
# returned by "find_blobs" below. Change "pixels_threshold" and "area_threshold" if you change the
# camera resolution. Don't set "merge=True" becuase that will merge blobs which we don't want here.

# create the pin to control the IR Leds

ir_led_pin = Pin("P3", Pin.OUT_PP, Pin.PULL_NONE)
# # #  = "P0" = id = pin name
# # # Pin.OUT_PP - configure the pin for output, with push-pull control;
# # # Pin.PULL_NONE - no pull up or down resistors;

# tell the sensor to enable the pin when the capturing starts
ir_led_pin.value(ir_led_active)
#ir_led_pin.high()
#ir_led_pin.off()
#sensor.set_vsync_output(ir_led_pin) # DON'T AUTOSYNC ANYMORE (need finer control for bg subtraction)

frameNumber = 0

##############################################################
#             I2C
##############################################################
# Code from https://github.com/openmv/openmv/blob/master/scripts/examples/02-Board-Control/arduino_i2c_slave.py

text = "Hello World!\n"
data = ustruct.pack("<%ds" % len(text), text)
# Use "ustruct" to build data packets to send.
# "<" puts the data in the struct in little endian order.
# "%ds" puts a string in the data stream. E.g. "13s" for "Hello World!\n" (13 chars).
# See https://docs.python.org/3/library/struct.html
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

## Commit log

2018-04-17 little fixes for finger messages
2018-05-15 fixed finger message when no finger is detected
2018-06-05 added bandpass filter to output
2018-11-16 added patch for testing actuators
2019-01-31 fixed finger measurement cleanup of codebase
2019-02-01 added additional screenshots and hardware objects that support usage of touchbox
    [ElektronicBox.blend, Enclosure.step, Enclosure.x_t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]
2019-02-01 fixed finger issue updated GUI screenshot
2019-08-22 update to gui and new calibration
2019-10-02 updated hardware list fixed arduino code for current arduino IDE (1.8.10)
    [TouchBox.ino]
2019-10-03 complete data chain is working
    [ElektronicBox.blend, TouchBox.blend]
2019-10-28 added PressureBase designs
    [PressureBase.step]
2019-10-28 added base files
    [Base.step]
2019-10-29 added IGES files
    [Base.iges, PressureBase.iges]
2019-10-29 added electronics files, updated base design
    [Base.iges, Base.step, LEDboard_v0.3-R001.brd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]
2019-10-31 new PressureBase design restructuring of design folder
    [Enclosure.step, Enclosure.x_t, LEDboard_v0.3-R001.brd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]
2019-11-01 cleanup, new screen shot, readme etc
    [LEDboard_v0.4-R001.brd, LEDboard_v0.4-R001.sch, board.fzz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]
2019-11-06 updated calibration for mk02
2023-07-21 Some updates for Mk03
    [Shield.step, Shield.x_t]
2023-07-23 Various updates for MK3
    [Shield.step, Shield.x_t]

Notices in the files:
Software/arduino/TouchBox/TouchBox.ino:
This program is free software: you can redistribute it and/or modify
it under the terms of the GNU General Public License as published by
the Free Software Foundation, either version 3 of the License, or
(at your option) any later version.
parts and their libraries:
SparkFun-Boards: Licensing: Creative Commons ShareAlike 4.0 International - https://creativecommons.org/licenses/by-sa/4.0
